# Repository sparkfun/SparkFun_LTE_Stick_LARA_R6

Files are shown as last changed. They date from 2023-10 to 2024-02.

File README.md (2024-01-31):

SparkFun LTE Stick - LARA-R6
========================================

SparkFun LTE Stick - LARA-R6 (https://www.sparkfun.com/products/23618)

[*SparkFun LTE Stick - LARA-R6 (CEL-23618)*](https://www.sparkfun.com/products/23618)

The SparkFun LTE Stick provides a development and prototyping platform for the LARA-R6 LTE Cat 1 module from u-blox<sup>&trade;</sup>. The LTE Stick uses the LARA-R6401 version, which supports both data and voice for North America and works with LTE bands used by these mobile networks: AT&T, Verizon, T-Mobile, and FirstNet. The board includes a nanoSIM card slot for users to select their preferred network. Check with your network provider for compatibility with the LARA-R6.

The LTE Stick routes the UART and I<sup>2</sup>S interfaces to a 0.1in.-spaced plated-through-hole (PTH) header along with the Reset and Power On signals. The board has two SMA connectors for the LARA-R6's primary and secondary antennas. The primary antenna sends and receives data, whereas the secondary antenna is receive only. Power to the board is provided either over the USB-C connector (recommended) or the VIN PTH pin (<b>6V Max</b>). The board defaults to use the higher voltage input. The board also includes test points for advanced users to solder to for the I<sup>2</sup>C interface, secondary UART, and four GPIO pins (IO1, IO2, IO3, and IO6).

Repository Contents
-------------------

* **/Documents** - Datasheets, additional product information 
* **/Examples** - Example code 
* **/Hardware** - Eagle design files (.brd, .sch)
* **/Production** - Production panel files (.brd)
* **/docs** - Documentation files for the LTE Stick - LARA-R6

Documentation
--------------

* **[Hookup Guide](https://docs.sparkfun.com/SparkFun_LTE_Stick_LARA_R6)** - Basic hookup guide for the SparkFun LTE Stick - LARA-R6.
* **[SparkFun u-blox Cellular Arduino Library](https://github.com/sparkfun/SparkFun_u-blox_Cellular_Arduino_Library)** - Arduino library for u-blox cellular modules including the LARA-R6.

Product Versions
----------------
* [CEL-23618](https://www.sparkfun.com/products/23618) - Initial release

License Information
-------------------

This product is _**open source**_! 

Please review the LICENSE.md file for license information. 

If you have any questions or concerns on licensing, please contact technical support on our [SparkFun forums](https://forum.sparkfun.com/viewforum.php?f=152).

Distributed as-is; no warranty is given.

- Your friends at SparkFun.

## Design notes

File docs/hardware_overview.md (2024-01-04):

---
icon: material/cog
---

## LARA-R6 LTE Module

The heart of the LTE Stick is the LARA-R6 LTE Cat 1 module from u-blox. The LARA-R6401 supports data, SMS, <i>and</i> voice over LTE bands and works with most major North American carriers (Verizon, TMobile, AT&T, etc.). 

<figure markdown>
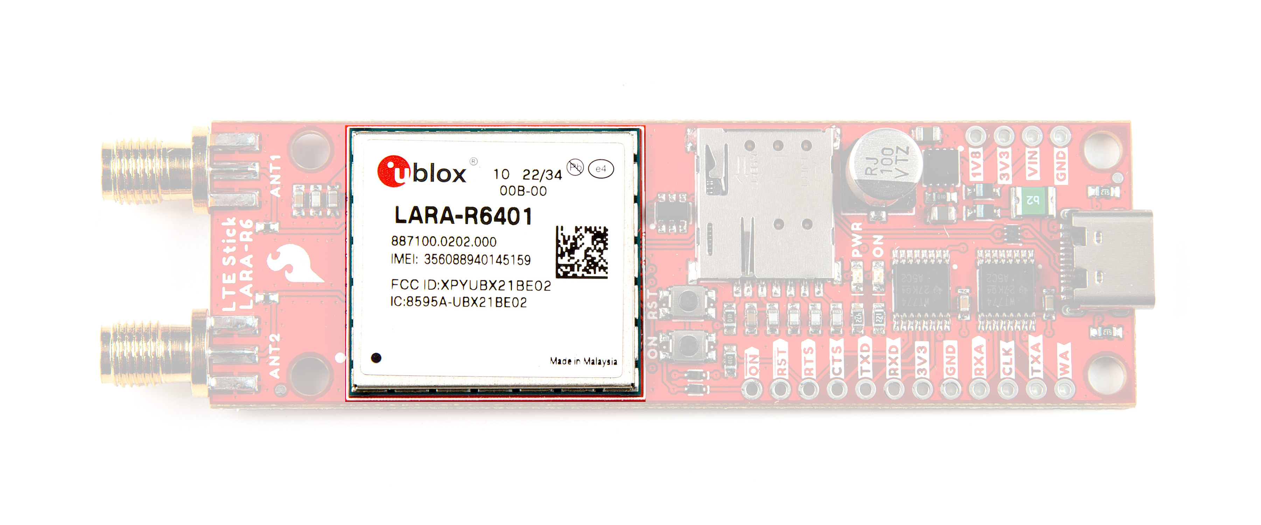
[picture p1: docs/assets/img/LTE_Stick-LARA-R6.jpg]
Highlighting the LARA-R6

</figure>

The LARA-R6 has the following interfaces: USB, 2x UART, I<sup>2</sup>S, I<sup>2</sup>C, SIM interface, and nine GPIO pins. It also has a host of features including device security through Root of Trust (RoT) with secure boot and update, firmware updates both over the air (uFOTA) and through AT commands, dynamic antenna tuning, jamming detection, and much more. For a complete overview of these features and other information on the LARA-R6401, refer to the [datasheet](./assets/component_documentation/LARA-R6-Datasheet.pdf). The R6401 supports LTE FDD bands from 600 MHz to 1900 MHz (2, 4, 5, 12, 13, 14, 66, and 71).

## Pinout

The board breaks out the LARA-R6's UART and I<sup>2</sup>S interfaces as well as the Power On, Reset and voltage pins to a pair of 0.1"-spaced PTH (plated through-hole) headers.

<figure markdown>
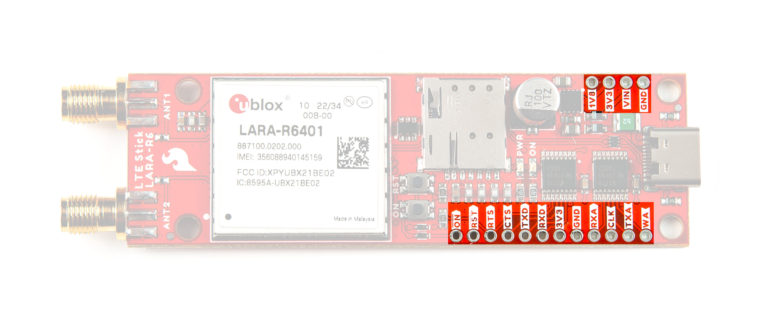
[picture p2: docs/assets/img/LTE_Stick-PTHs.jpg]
Highlighting PTH pinout

</figure>

The list below outlines the functionality of pins broken out on the LTE Stick:

  * PWR_On - LARA-R6 power control pin
  * Reset - LARA-R6 reset pin
  * RXD - UART data out
  * TXD - UART data in
  * CTS - UART clear to send
  * RTS - UART ready to send
  * RXA - I<sup>2</sup>S receive data
  * CLK - I<sup>2</sup>S clock
  * TXA - I<sup>2</sup>S transmit data
  * WA - I<sup>2</sup>S word alignment

  * VIN - 5V 
  * 3.3V - Regulated 3.3V
  * 1.8 - Regulated 1.8V  
 
### Test Points

!!! warning
	All three of these clusters have test point connections for <b>1.8V</b> and <b>GND</b> and connect directly to the associated pins on the LARA-R6. These pins are <i>not</i> level-shifted and run at <b>1.8V</b> logic. Take care when interacting with these pins to avoid damaging the signals they connect to.

The LTE Stick also has several other interfaces broken out to test points for advanced users to solder to. These test points are small copper pads grouped into three clusters labeled: <b>I2C</b>, <b>GPIO</b>, and <b>UART2</b>. They do not have individual pin labels so refer to the [board files (ZIP)](./assets/board_files/SparkFun_LTE_Stick_LARA_R6.zip) to identify the pin locations.

<figure markdown>
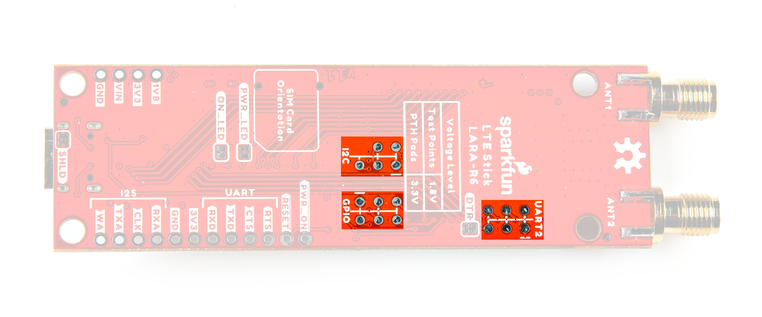
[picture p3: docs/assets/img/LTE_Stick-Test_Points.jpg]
Highlighting the test point clusters

</figure>

The I2C cluster contains the LARA's I<sup>2</sup>C bus pins (SDA/SCL) as well as GPIO4. The GPIO cluster contains GPIO1, GPIO2, GPIO3, and GPIO6. All GPIO pins can act as a generic GPIO signal but some have alternate functions outlined in section 2.8 of the [LARA-R6 datasheet](./assets/component_documentation/LARA-R6-Datasheet.pdf). 

The UART2 cluster contains the LARA's UART2 pins: TX2, RX2, CTS2, and RTS2. This interface is disabled by default and can be activated by the dedicated AT command. Refer to section 18.12 of the [AT commands manual](./assets/component_documentation/LARA-R6-L6-AT-Commands.pdf) and section 1.9.1.2 of the [integration manual](./assets/component_documentation/LARA-R6-L6-Integration-Manual.pdf) for complete information on using these pins. Users also should open the <b>DTR</b> solder jumper to use this pin for TX2 (refer to the Solder Jumpers section for more information on the DTR jumper).

## Connectors/Connections

Let's take a closer look at the connectors on the LTE Stick.

### Power

The LTE Stick uses a USB-C connector for primary power input and serial communication. The board also has dedicated PTHs for the three voltage inputs on the board: <b>5V(VIN)</b>, <b>3.3V</b>, and <b>1.8V</b> along with PTHs for Ground.

<figure markdown>
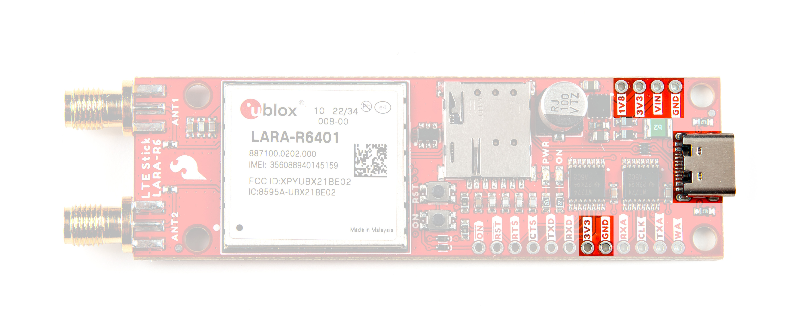
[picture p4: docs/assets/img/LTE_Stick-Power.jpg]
Highlighting the USB-C connector & power PTHs

</figure>

### Antenna Connections

The LARA-R6 has two antenna connections; Primary (ANT1) and Secondary (ANT2). The Primary antenna functions as the main antenna interface and supports TX/RX transmissions. The Secondary antenna communicates over RX only for the LTE / 3G RX diversity configuration. 

<figure markdown>
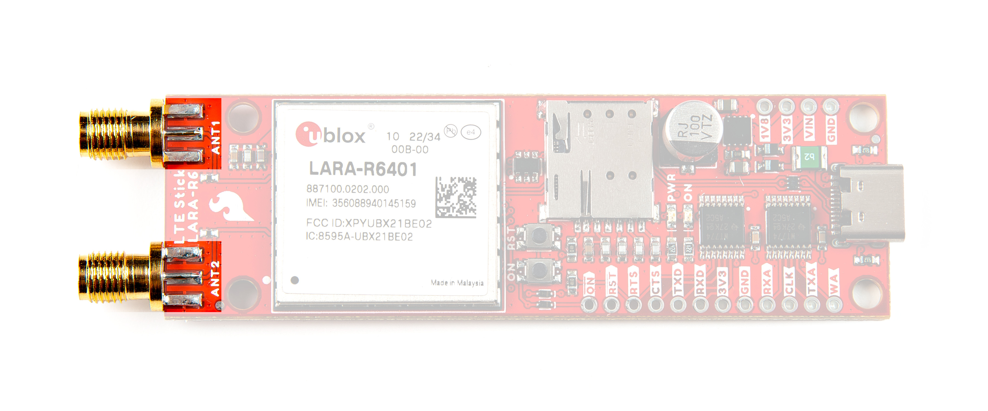
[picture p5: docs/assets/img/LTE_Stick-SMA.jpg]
Highlighting the antenna SMA connectors

</figure>

### Nano SIM Card Slot

The LTE Stick has an on-board Nano SIM card slot. The LTE Stick uses the LARA-R6401 which works with most major North American carriers (Verizon, TMobile, AT&T, etc.).   

<figure markdown>
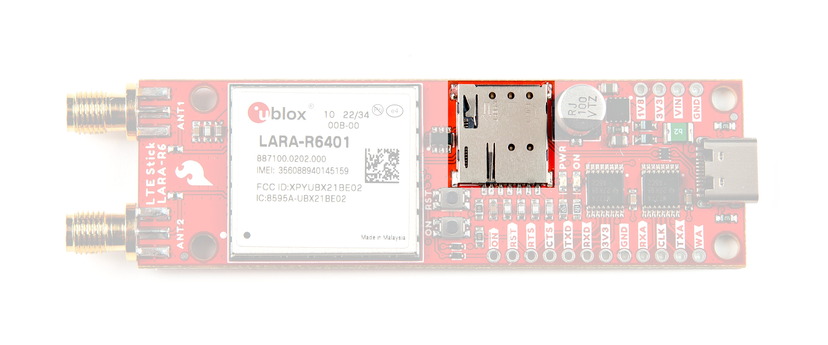
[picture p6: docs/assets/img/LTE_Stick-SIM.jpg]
Highlighting the nano SIM card slot

</figure>

## Buttons

The board has two buttons labeled <b>ON</b> and <b>RST</b>. The <b>ON</b> button connects to the LARA-R6 PWR_On pin which turns the module on and off. Tap it once to turn the module on and hold it down for three seconds to turn it off. The <b>RST</b> button connects to the LARA-R6's reset line and resets the module when pressed.

<figure markdown>
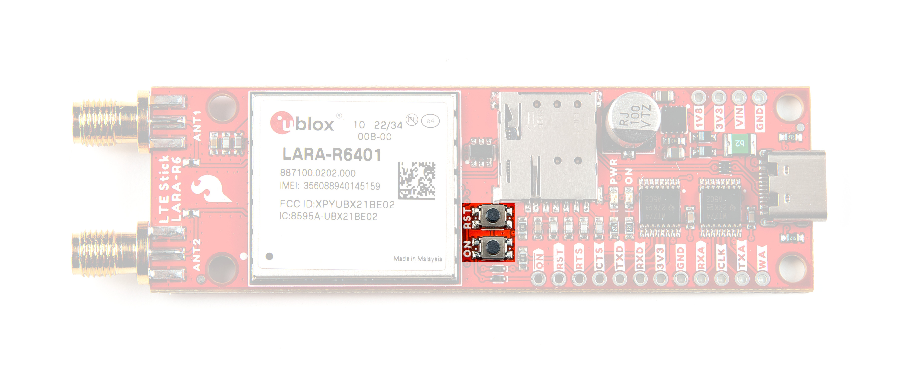
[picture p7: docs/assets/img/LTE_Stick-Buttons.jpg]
Highlighting the Reset and On buttons

</figure>

## LEDs

The LTE Stick has a pair of red LEDs labeled <b>PWR</b> and <b>ON</b>. The <b>PWR</b> LED indicates whenever the 3.3V rail is powered through USB or the VIN/3.3V PTH pins. The <b>ON</b> LED indicates when the LARA-R6 is powered up. 

<figure markdown>
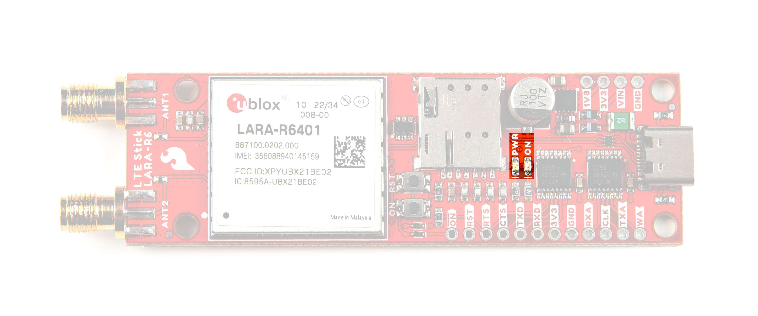
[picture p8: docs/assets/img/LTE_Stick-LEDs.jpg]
Highlighting the Power and On LEDs

</figure>

## Solder Jumpers

??? note "Never modified a jumper before?"
	Check out our <a href="https://learn.sparkfun.com/tutorials/664">Jumper Pads and PCB Traces tutorial</a> for a quick introduction!
	<p align="center">
		<a href="https://learn.sparkfun.com/tutorials/664">
		Tutorial's thumbnail<br>
        How to Work with Jumper Pads and PCB Traces</a>
	</p>

The LTE Stick has four solder jumpers labeled <b>PWR_LED</b>, <b>ON_LED</b>, <b>SHLD</b>, and <b>DTR</b>. 

<figure markdown>
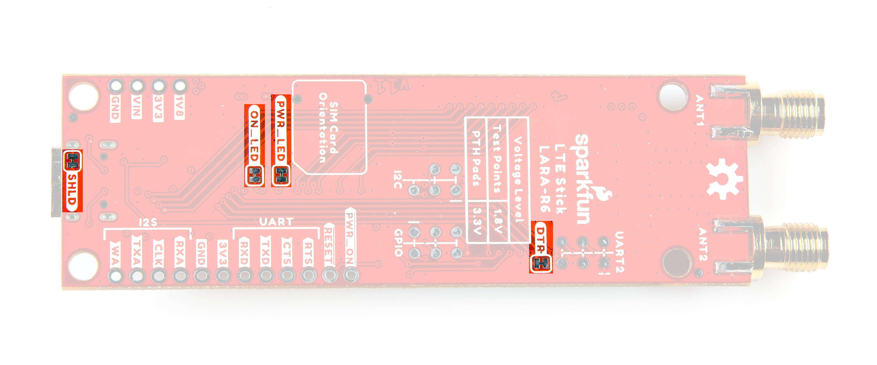
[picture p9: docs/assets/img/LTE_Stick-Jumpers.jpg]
Highlighting the solder jumpers

</figure>

The <b>PWR_LED</b> and <b>ON_LED</b> jumpers complete the power circuits for their associated LEDs (PWR and ON). They are CLOSED by default. Open them to disable these LEDs to help conserve power. The <b>SHLD</b> jumper connects the USB-C connector's shield pin to ground. Open it to isolate the shield pin. The <b>DTR</b> jumper is CLOSED by default and pulls the LARA-R6 DTR pin to ground (LOW) to function as UART data terminal ready. Open the jumper to use the DTR pin for its secondary use as TX2 when using the UART2 test point cluster.

## Board Dimensions

The board measures 3.25" x 1.00" (82.55mm x 25.40mm) with four mounting holes that fit a [4-40 screw](https://www.sparkfun.com/products/10453).

<figure markdown>
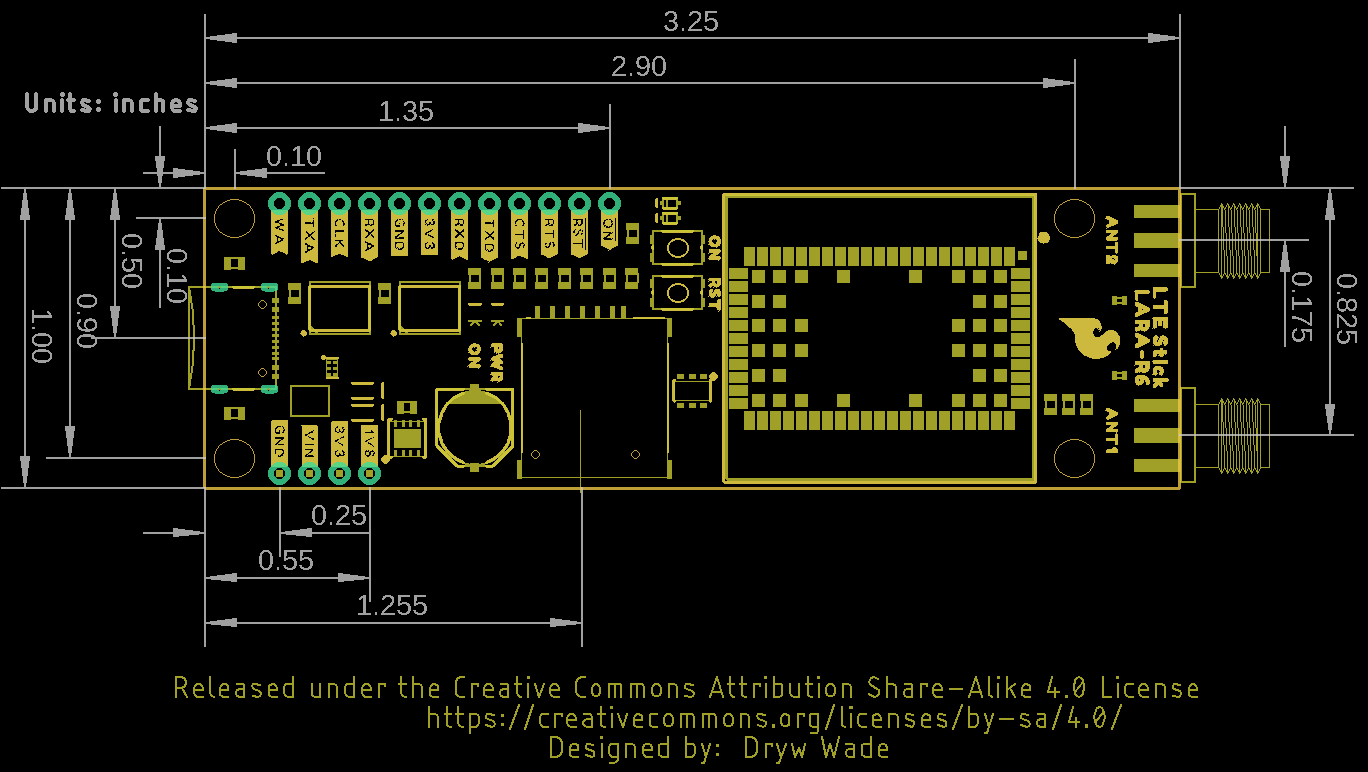
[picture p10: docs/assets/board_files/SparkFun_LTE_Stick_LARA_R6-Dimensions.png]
Board Dimensions

<figcaption markdown>
[Board dimensions](./assets/board_files/SparkFun_LTE_Stick_LARA_R6-Dimensions.png) for the SparkFun LTE Stick, in inches.
</figcaption>
</figure>

??? tip "Need more measurements?"
	For more information about the board's dimensions, users can download the [Eagle files](./assets/board_files/SparkFun_LTE_Stick_LARA_R6.zip) for the board. These files can be opened in Eagle and additional measurements can be made with the dimensions tool.

	??? info ":octicons-download-16:{ .heart } Eagle - Free Download!"
		Eagle is a [CAD]("computer-aided design") program for electronics that is free to use for hobbyists and students. However, it does require an account registration to utilize the software.

		<center>
		[Download from<br>:autodesk-primary:{ .autodesk }](https://www.autodesk.com/products/eagle/free-download "Go to downloads page"){ .md-button .md-button--primary width="250px" }
		</center>
	
	??? info ":straight_ruler: Dimensions Tool"
		This video from Autodesk demonstrates how to utilize the dimensions tool in Eagle, to include additional measurements:

		<center>
		<div class="video">
		<iframe src="https://www.youtube.com/embed/dZLNd1FtNB8" title="EAGLE Dimension Tool" frameborder="0" allow="accelerometer; autoplay; clipboard-write; encrypted-media; gyroscope; picture-in-picture" allowfullscreen></iframe>
		</div>
		</center>

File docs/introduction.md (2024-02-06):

---
icon: material/book-open-page-variant
---

<div class="grid cards desc" markdown>

-    <a href="https://www.sparkfun.com/products/23618">
    **SparkFun LTE Stick - LARA-R6**<br>
    **SKU:** CEL-23618

    ---

    <figure markdown>
    Product Thumbnail
    </figure></a>

    <center>
    <article class="video_desc">
    <iframe src=" https://www.youtube.com/embed/hY0C0PU3CvQ" title="Product Showcase: SparkFun LTE Stick - LARA-R6" frameborder="0" allow="accelerometer; autoplay; clipboard-write;encrypted-media; gyroscope; picture-in-picture" allowfullscreen></iframe>
    </article>
    </center>

-    The SparkFun LTE Stick - LARA-R6 is a development and prototyping platform for the LARA-R6401 LTE module from ublox<sup>&trade;</sup>. The LTE Stick uses the LARA-R6401 version which supports both data and voice for North America and works with LTE bands used by these mobile networks: AT&T, Verizon, T-Mobile, and FirstNet. The board includes a nanoSIM card slot for users to select their preferred network. Check with your network provider for compatibility with the LARA-R6.

    The LARA-R6 workss on multiple LTE FDD frequency bands (2, 4, 5, 12, 13, 14, 66, and 71) and includes a host of common features users expect from u-blox modules including uFOTA (over-the-air firmware update), Root of Trust, secure boot/update, jamming detection, antenna and SIM detection, and much more. 
    
    The LTE Stick routes the UART and I<sup>2</sup>S interfaces to a 0.1"-spaced plated-through-hole (PTH) header along with the Reset and Power On signals and we designed the board to specifically mount on to a breadboard for easy prototyping. The board has two SMA connectors for the LARA-R6's primary and secondary antennas.

    <center>
    [Purchase from SparkFun :fontawesome-solid-cart-plus:{ .heart }](https://www.sparkfun.com/products/23618){ .md-button .md-button--primary }
    </center>

</div>

## Required Materials

The LTE Stick requires a few peripheral items including antennas, USB-C cable, and supported SIM card to get it up and running. Below are a few recommended options for each.

### USB-C Cable

For basic use and conifguration of the LTE Stick using AT commands or u-blox's m-center software you'll need USB-C cable to connect the dev board to your computer:

<div class="grid cards" markdown>

-   <a href="https://www.sparkfun.com/products/14743">

    <figure markdown>
    USB 3.1 Cable A to C - 3 Foot
    </figure>
    </a>
    ---
    <a href="https://www.sparkfun.com/products/14743">
    **USB 3.1 Cable A to C - 3 Foot**<br>
    CAB-14743
    </a>

-   <a href="https://www.sparkfun.com/products/15424">
    
    <figure markdown>
    Reversible USB A to C Cable - 2m
    </figure>
    </a>
    ---
    <a href="https://www.sparkfun.com/products/15424">
    **Reversible USB A to C Cable - 2m**<br>
    CAB-15424
    </a>
</div>

### LTE Antenna

The LTE Stick has two SMA connectors for the Primary and Secondary antenna signals on the LARA-R6. The LARA-R6 only requires the Primary antenna for basic functionality but u-blox recommends connecting the Secondary antenna for best signal quality. We recommend using an antenna like the one below:

<div class="grid cards" markdown>

-   <a href="https://www.sparkfun.com/products/16432">

    <figure markdown>
    LTE Hinged External Antenna - 698MHz-2.7GHz, SMA Male
    </figure>
    </a>
    ---
    <a href="https://www.sparkfun.com/products/16432">
    **LTE Hinged External Antenna - 698MHz-2.7GHz, SMA Male**<br>
    CEL-16432
    </a>
</div>

### SIM Card

Finally, the LTE Stick requires a nano SIM card for cellular network connectivity. As mentioned above, the LTE Stick uses the LARA-R6401 module and supports <i>only</i> North American LTE networks and works with the AT&T, Verizon, T-Mobile, and FirstNet cellular networks though make sure to check with your selected network provider for compatibility with the LARA-R6 before purchasing. The Hologram SIM card listed below works with the LARa-R6 for data and receiving SMS but not voice or sending SMS:

<div class="grid cards" markdown>

-   <a href="https://www.sparkfun.com/products/17117">

    <figure markdown>
    Hologram SIM Card
    </figure>
    </a>
    ---
    <a href="https://www.sparkfun.com/products/17117">
    **Hologram SIM Card**<br>
    CEL-17117
    </a>
</div>

## Optional Materials

Using the LTE Stick with the SparkFun u-blox Cellular Arduino Library requires a connection to a microcontroller/development board. Below are a few options that will work with the LTE Stick out of the box.

### Development Boards

??? warning "Logic Levels"
    The LTE Stick operates at <b>3.3V</b> logic so make sure your chosen development board operates at the same logic level or use a [level shifter](https://www.sparkfun.com/categories/361).

<div class="grid cards" markdown>

-   <a href="https://www.sparkfun.com/products/20168">

    <figure markdown>
    SparkFun Thing Plus - ESP32 WROOM (USB-C)
    </figure>
    </a>
    ---
    <a href="https://www.sparkfun.com/products/20168">
    **SparkFun Thing Plus - ESP32 WROOM (USB-C)**<br>
    DEV-20168
    </a>

-   <a href="https://www.sparkfun.com/products/19177">

    <figure markdown>
    SparkFun IoT RedBoard - ESP32 Development Board
    </figure>
    </a>
    ---
    <a href="https://www.sparkfun.com/products/19177">
    **SparkFun IoT RedBoard - ESP32 Development Board**<br>
    DEV-19177
    </a>

-   <a href="https://www.sparkfun.com/products/15574">
    
    <figure markdown>
    SparkFun Thing Plus - Artemis
    </figure>
    </a>
    ---
    <a href="https://www.sparkfun.com/products/15574">
    **SparkFun Thing Plus - Artemis**<br>
    DEV-18158
    </a>

-   <a href="https://www.sparkfun.com/products/20168">

    <figure markdown>
    SparkFun Qwiic Pocket Development Board - ESP32-C6
    </figure>
    </a>
    ---
    <a href="https://www.sparkfun.com/products/22925">
    **SparkFun Qwiic Pocket Development Board - ESP32-C6**<br>
    DEV-22925
    </a>

-   <a href="https://www.sparkfun.com/products/23386">

    <figure markdown>
    SparkFun ESP32 Qwiic Pro Mini
    </figure>
    </a>
    ---
    <a href="https://www.sparkfun.com/products/23386">
    **SparkFun ESP32 Qwiic Pro Mini**<br>
    DEV-23386
    </a>

-   <a href="https://www.sparkfun.com/products/15444">

    <figure markdown>
    SparkFun RedBoard Artemis
    </figure>
    </a>
    ---
    <a href="https://www.sparkfun.com/products/15444">
    **SparkFun RedBoard Artemis**<br>
    DEV-15444
    </a>    
</div>

If you prefer to use the LTE Stick with a development board or simply prefer a soldered connection or want to modify the solder jumpers on these Qwiic breakouts you you may need some of the products listed below:

## Soldering Tools & Accessories

<div class="grid cards" markdown align="center">

-   <a href="https://www.sparkfun.com/products/116">

    <figure markdown>
    Break Away Headers - Straight)
    </figure>
    </a>
    ---
    <a href="https://www.sparkfun.com/products/116">
    **Break Away Headers - Straight**<br>
    PRT-00116
    </a>

-   <a href="https://www.sparkfun.com/products/14681">
    
    <figure markdown>
    SparkFun Beginner Tool Kit
    </figure>
    </a>
    ---
    <a href="https://www.sparkfun.com/products/14681">
    **SparkFun Beginner Tool Kit**<br>
    TOL-14681
    </a>

-   <a href="https://www.sparkfun.com/products/22133">

    <figure markdown>
    Weller WLSK3012A Soldering Station
    </figure>
    ---
    <a href="https://www.sparkfun.com/products/22133">**Weller WLSK3012A Soldering Station**<br>
    TOL-22133
    </a>

-   <a href="https://www.sparkfun.com/products/9325">

    <figure markdown>
    Solder Lead Free - 100-gram Spool
    </figure>
    ---
    <a href="https://www.sparkfun.com/products/9325">**Solder Lead Free - 100-gram Spool**<br>
    TOL-09325
    </a>

-   <a href="https://www.sparkfun.com/products/9200">
    
    <figure markdown>
    Hobby Knife
    </figure>
    </a>
    ---
    <a href="https://www.sparkfun.com/products/9200">
    **Hobby Knife**<br>
    TOL-09200
    </a>

-   <a href="https://www.sparkfun.com/products/14579">

    <figure markdown>
    Chip Quik No-Clean Flux Pen - 10mL
    </figure>
    </a>
    ---
    <a href="https://www.sparkfun.com/products/14579">**Chip Quik No-Clean Flux Pen - 10mL**<br>
    CAB-14579
    </a>
</div>

## Suggested Reading

Before getting started with this Hookup Guide, you may want to read through the tutorials below if you are not familiar with the concepts covered in them or want a refresher. If you are using either of the Qwiic Shields linked above, we recommend reading through their respective Hookup Guides before continuing with this tutorial:

<div class="grid cards hide col-4" markdown align="center">

-   <a href="https://learn.sparkfun.com/tutorials/8">
    <figure markdown>
    Serial Communication
    </figure>
    </a>
    <a href="https://learn.sparkfun.com/tutorials/8">**Serial Communication**
    </a>

-   <a href="https://learn.sparkfun.com/tutorials/62">
    <figure markdown>
    Logic Levels
    </figure>
    </a>
    <a href="https://learn.sparkfun.com/tutorials/62">**Logic Levels**
    </a>

-   <a href="https://learn.sparkfun.com/tutorials/61">
    <figure markdown>
    Installing Arduino IDE
    </figure>
    </a>
    <a href="https://learn.sparkfun.com/tutorials/61">**Installing Arduino IDE**
    </a>

-   <a href="https://learn.sparkfun.com/tutorials/15">
    <figure markdown>
    Installing an Arduino Library
    </figure>
    </a>
    <a href="https://learn.sparkfun.com/tutorials/15">**Installing an Arduino Library**
    </a>

-   <a href="https://learn.sparkfun.com/tutorials/112">
    <figure markdown>
    Serial Terminal Basics
    </figure>
    </a>
    <a href="https://learn.sparkfun.com/tutorials/112">**Serial Terminal Basics**
    </a>

-   <a href="https://learn.sparkfun.com/tutorials/664">
    <figure markdown>
    How to Work with Jumper Pads and PCB Traces
    </figure>
    </a>
    <a href="https://learn.sparkfun.com/tutorials/664">**How to Work with Jumper Pads and PCB Traces**
    </a>
</div>

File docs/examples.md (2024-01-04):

---
icon: simple/arduino
---

The SparkFun u-blox Cellular Arduino Library includes a large set of examples to do all sorts of things with supported u-blox cellular modules. Some examples work with all modules, others are limited to specific ones. All examples assume a serial connection between a microcontroller and the LTE Stick (or other supported cellular module) as demonstrated in the Hardware Assembly section. These examples build upon each other so we recommend following them in sequential order to get everything set up and working properly.

!!! note "LARA-R6 Power"
	Make sure to power on the module using the "ON" button 

If you have not used m-center or AT commands to configure the network information and register the network operator for your device before using this library, you may need to go through Example 2 - Network Info and Example 3 - Register Operator to get the LARA-R6 registered and configured properly on your network. Otherwise, feel free to skip ahead to the Ping and other more complex examples.

## Example 1 - Device Identification

The first example  performs the basic AT commands to return the device information of a connected module:

* Manufacturer ID
* Model
* Firmware Version
* Serial Number
* IMEI ID
* IMSI ID
* SIM CCID
* Subscriber Number (from the SIM)
* Capabilities
* SIM state

Open the example by navigating to <b>File < Examples < SparkFun u-blox Cellular Arduino Library < Example 1 - Device Identification</b> or copy the code below into a blank sketch.

??? "Example 1 - Device Information"
	```
	--8<-- "https://raw.githubusercontent.com/sparkfun/SparkFun_u-blox_Cellular_Arduino_Library/main/examples/Example1_DeviceIdentification/Example1_DeviceIdentification.ino"
	```

!!! warning "Serial Port Selection"
	This and all following examples default to use <code>Serial1</code> for serial communication between the LTE Stick and microcontroller. If your selected microcontroller does not have this serial port, uncomment the following line and, if necessary, adjust the pins set for software serial depending on the [software serial library limitations](https://docs.arduino.cc/learn/built-in-libraries/software-serial).

	```c++
		// SoftwareSerial mySerial(16, 17);
	```

Select your board (SparkFun Thing Plus ESP32 if you're following along with this tutorial verbatim) and Port and click the "Upload" button. When the code finishes compiling and uploading, open the [serial monitor](https://learn.sparkfun.com/tutorials/terminal-basics/arduino-serial-monitor-windows-mac-linux) with the baud set to <b>115200</b>. The code waits on a user prompt to begin so press any key when prompted in the serial monitor and you should see the device information and SIM status print out.

## Example 2 - Network Info

The second example verifies the LARA-R6 is receiving an LTE signal on a selected network and prints out the network information and IDs. The code creates the LARA-R6 object and assigns a network operator value.

??? "Example 2 -Network Info"
	```
	--8<-- "https://raw.githubusercontent.com/sparkfun/SparkFun_u-blox_Cellular_Arduino_Library/main/examples/Example2_NetworkInfo/Example2_NetworkInfo.ino"
	```

After uploading the code, open a terminal window with the baud set to <b>115200</b> and enter any key to start the example. After initializing everything needed, the code attempts to set the Network Profile to the Mobile Network Operator entered. If successful, the code prints out the RSSI (Received Signal Strength), Network Registration Status and Context IDs, Access Point Names and IP Addresses.

## Example 3 - Register Operator

Example 4 checks to see if the LARA-R6 is connected to a network and lets you register on a different network if available and if the SIM supports this. This example can also be used to list all the LTE operators the LARA-R6 can detect. Note, you can only connect to networks supported by your SIM card. Refer to your SIM card manufacturer's documentation for supported networks.

??? "Example 3 - Register Operator"
	```
	--8<-- "https://raw.githubusercontent.com/sparkfun/SparkFun_u-blox_Cellular_Arduino_Library/main/examples/Example3_RegisterOperator/Example3_RegisterOperator.ino"
	```	

## Example 5 - Ping

The eighth example tests the LTE Stick's data connection by a standard server ping. Open a terminal window and follow the prompts then enter a server to ping. Any valid web address like <b>www.google.com</b> or <b>www.sparkfun.com</b> works. If the ping succeeds the code prints out the time to send and receive the ping in milliseconds.

??? "Example 5 - Ping"
	```
	--8<-- "https://raw.githubusercontent.com/sparkfun/SparkFun_u-blox_Cellular_Arduino_Library/main/examples/Example5_Ping/Example5_Ping.ino"
	```

If the ping fails, try uncommenting this line that enables debugging over serial:

```c++
// myModule.enableDebugging(); // Uncomment this line to enable helpful debug messages on Serial
```

Upload the code again, retry the ping and look for any messages that include +UUPINGER:. Refer to the list of Ping error codes in Appendix A. 9 of the [AT Command Reference](./assets/component_documentation/LARA-R6-L6-AT-Commands.pdf) to decipher the error code.

## Further Examples

These examples perform the basic tests for making sure everything is working properly on the LTE Stick but the SparkFun u-blox Cellular Arduino Library includes many more examples to take full advantage of the LARA-R6's capabilities including audio examples for playing audio tones and phonecall control. The audio examples require external hardware including an audio codec and are beyond the scope of this tutorial.

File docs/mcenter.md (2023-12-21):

The m-center application from u-blox is an excellent configuration and interaction tool for the LARA-R6 (and other cellular modules). It is only available on Windows so if you have a different operating system, you'll need to use another software solution like the SparkFun u-blox AT Command Arduino Library covered in the next sections. This section only covers a few of the basics to get started using the LTE Stick with m-center. Refer to u-blox's [m-center User Guide](https://www.u-blox.com/en/m-center-user-guide) for a complete overview of all of the application's features.

## Download m-center

The m-center application is available from u-blox [here](https://www.u-blox.com/en/product/m-center). Click the button on that page to download the installer. Locate that file and follow the instructions to finish the installation process.

<center>
[u-blox m-center](https://www.u-blox.com/en/product/m-center){ .md-button .md-button--primary }
</center>

### Download Windows Drivers

The LARA-R6 also requires a Windows USB driver download. Find it on u-blox's [LARA-R6 Documentation & Resources](https://www.u-blox.com/en/product/lara-r6-series?legacy=Current#Documentation-&-resources) page or download the driver ZIP directly by clicking the button below:

<center>
[u-blox LARA-R6 Windows Driver (ZIP)](https://content.u-blox.com/sites/default/files/2023-10/ublox_R4_R6_L6_windows_3264_v2.0.0.0.zip){ .md-button .md-button--primary }
</center>

Open the file once it downloads and follow the instructions to complete the driver installation.

## Basic LTE Stick Connection & Testing

Now that everything is downloaded connect the LTE Stick over USB and press the "On" button to power up the LARA-R6, open m-center and you'll see this menu:

<div markdown>
<figure markdown>
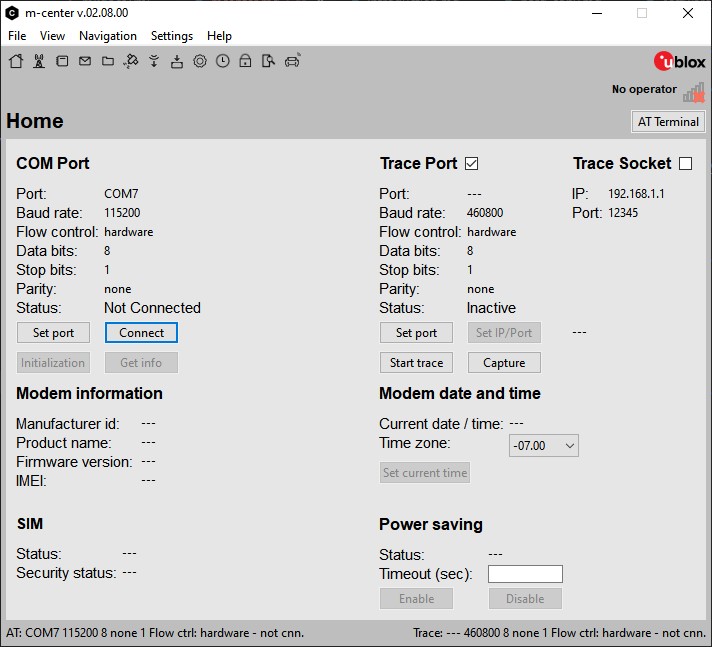
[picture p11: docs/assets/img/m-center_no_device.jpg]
Main m-center menu

</figure>
</div>

Next, click the "Set Port" button to select the COM port the LTE Stick is on. The LTE Stick has four port options in this menu as the screenshot below shows. Select the one for USB1 (labeled "u-blox Modem USB1 AT and Data (COM#) or similar) and click "Connect". If you do not see any devices available or see unrelated ports, make sure the "ON" LED is illuminated on the LTE Stick and that the drivers finished installing.

<div markdown>
<figure markdown>
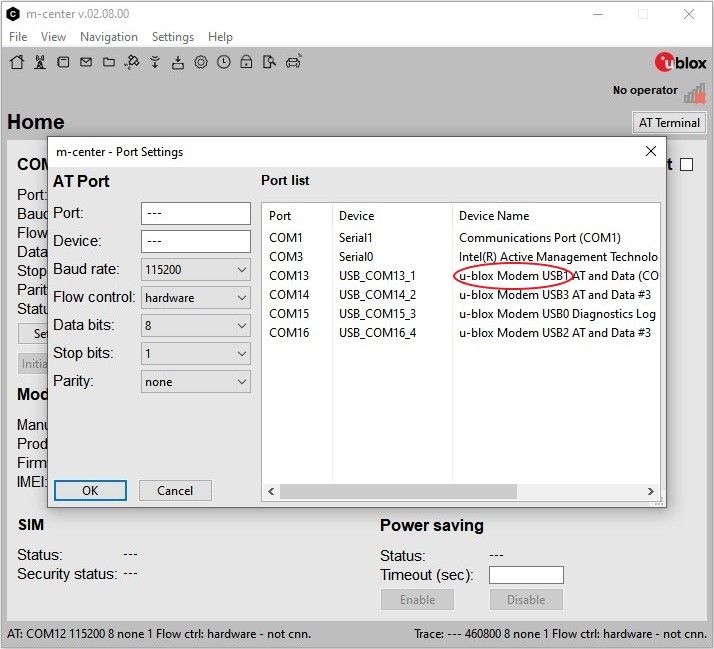
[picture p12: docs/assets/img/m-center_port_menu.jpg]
Main m-center menu

</figure>
</div>

After the board connects, m-center will display the LARA-R6's modem information including manufacturer, device ID, and firmware version. It also opens the terminal interface and prints out the device's response to the Generic set of AT commands similar to the screenshot below:

<div markdown>
<figure markdown>
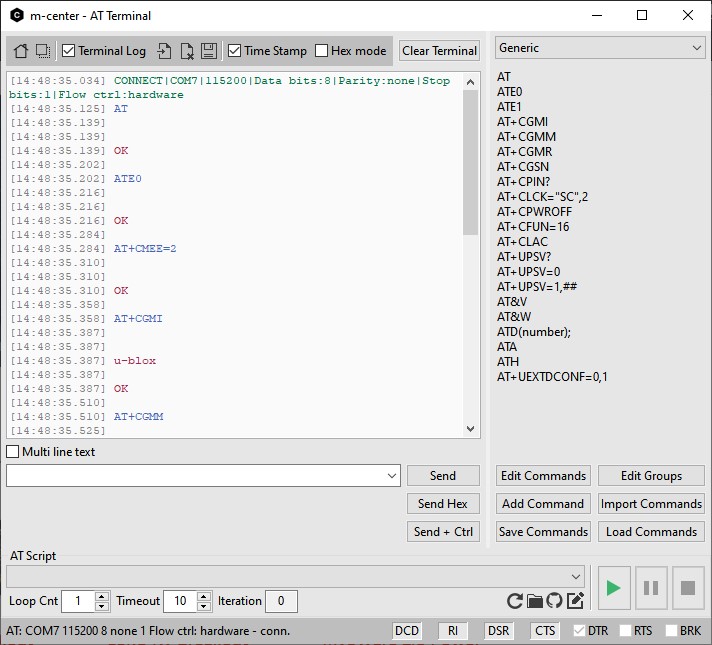
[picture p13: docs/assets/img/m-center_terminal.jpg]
Main m-center menu

</figure>
</div>

This basic printout lets you know most things are working but the main m-center menu also has several tabs at the top for testing other things such as network connection, firmware update (FOTA or AT command), SMS messages, and more. You can also click the "Initialization" button to initialize the LARA-R6 again or the "Get info" button to refresh the modem information and SIM status.

## Network & Operator Setup

Now that we have the LTE Stick connected and reporting the correct device information, it's time to connect to the cellular network and select the operator. Click the "Cell Tower" image in the top left to switch to the Network tab. In this tab, we can get the network information and operators list as well as the PSD (packet-switched-data profiles) though the PSD profiles are not necessary for basic use of the LARA-R6.

<div markdown>
<figure markdown>
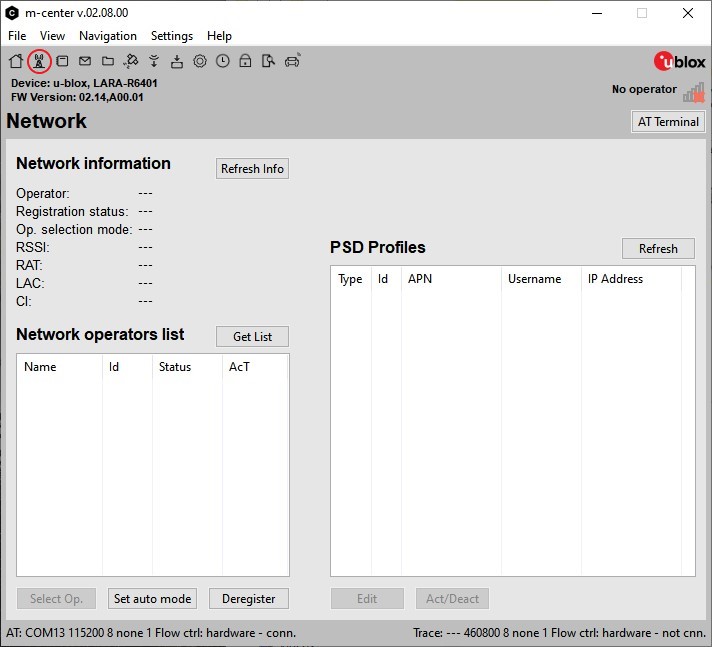
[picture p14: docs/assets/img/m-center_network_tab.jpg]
Main m-center menu

</figure>
</div>

Click the "Get List" button to have the LARA-R6 report all available network operators for the connected SIM card. If no operators are selected, choose an available/preferred operator and you're all set to move on to using the LTE Stick on your cellular network. 

<div markdown>
<figure markdown>
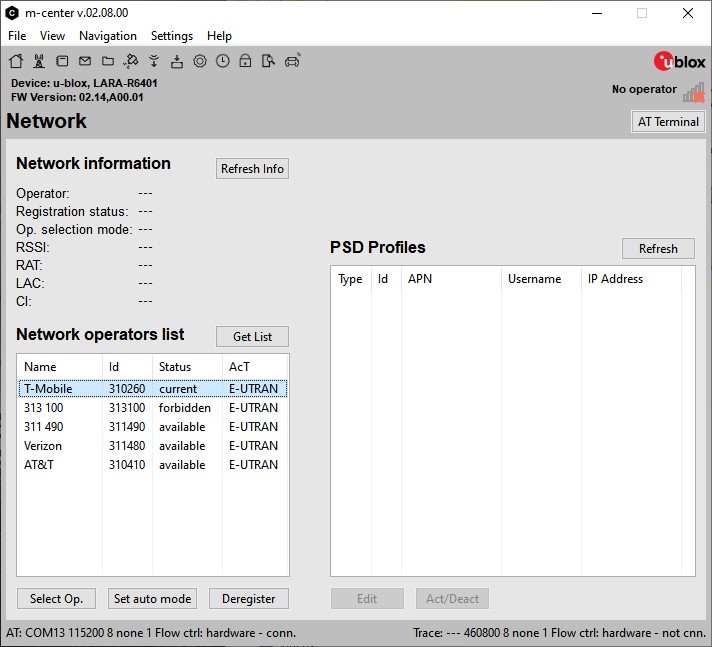
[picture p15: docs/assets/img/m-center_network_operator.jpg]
Main m-center menu

</figure>
</div>

That covers the basics of getting started with m-center. For more information, check out u-blox's [m-center user guide](https://www.u-blox.com/en/m-center-user-guide) or read on to the next section to learn how to use the LTE Stick with Arduino and the SparkFun u-blox Cellular Arduino Library.

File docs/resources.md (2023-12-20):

# Resources
For more resources related to the LTE Stick - LARA-R6, check out the links listed here: 

<b>LTE Stick Resources:</b>

* [Product Page](https://www.sparkfun.com/products/23618)
* [Schematic](./assets/board_files/SparkFun_LTE_Stick_LARA_R6.pdf)
* [Eagle Files](./assets/board_files/SparkFun_LTE_Stick_LARA_R6.zip) 
* [Board Dimensions]()
* [SparkFun u-blox Cellular Arduino Library](https://github.com/sparkfun/SparkFun_u-blox_Cellular_Arduino_Library)
* [Hardware GitHub Respository](https://github.com/sparkfun/SparkFun_LTE_Stick_LARA_R6)

<b>LARA-R6 Resources:</b>

* [Datasheet](./assets/component_documentation/LARA-R6-Datasheet.pdf)
* [Integration Manual](./assets/component_documentation/LARA-R6-L6-Integration-Manual.pdf)
* [Audio App Note](./assets/component_documentation/LARA-R6-Audio-App-Note.pdf)
* [AT Command Set](./assets/component_documentation/LARA-R6-L6-AT-Commands.pdf)
* [m-center Download](https://www.u-blox.com/en/product/m-center)
* [m-center User Guide](https://www.u-blox.com/en/m-center-user-guide)

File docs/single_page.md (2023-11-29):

---
hide:
  - navigation
  - toc
icon: fontawesome/solid/scroll
---

--8<-- "./docs/introduction.md:5"

# Hardware Overview
--8<-- "./docs/hardware_overview.md:5"

# Hardware Assembly
--8<-- "./docs/hardware_assembly.md:5"

# u-blox Cellular Arduino Library

## Software Setup
--8<-- "./docs/software_setup.md:5"

## Arduino Examples
--8<-- "./docs/examples.md"

# Troubleshooting Tips
--8<-- "./docs/troubleshooting_tips.md:5"

# Resources:
--8<-- "./docs/resources.md"

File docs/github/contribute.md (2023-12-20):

# Contribute: Make an Augmentation!
Spot an improvement opportunity? Feel free to contribute to our open-source design and documentation. 

## :material-file-document-multiple:&nbsp;Improve our Documentation
All of this documentation can be modified by you! Please help us make it better.

* These pages are contained in the [`docs` folder](https://github.com/sparkfun/SparkFun_LTE_Stick_LARA_R6/tree/main/docs) of the [SparkFun LTE Stick - LARA-R6 repository](https://github.com/sparkfun/SparkFun_LTE_Stick_LARA_R6).

<!-- ### :material-source-pull:&nbsp;Submit a Correction -->
### Submit a Correction

1. With a GitHub account, [fork this repository](https://github.com/sparkfun/SparkFun_LTE_Stick_LARA_R6/fork).
2. Add your corrections or improvements to the markdown file.
3. File a pull request with your changes, and enjoy making the ~~words~~ ~~worlds~~ world a better place.
	* Once received, the documentation specialist will automatically be notified.
	* We will review your suggested improvements to make sure they are correct and fit within our documentation standards.

## :material-cog:&nbsp;Improve our Hardware Design
All of our designs are open-source! Please help us make it better.

* Our board design files are contained in the [`Hardware` folder](https://github.com/sparkfun/SparkFun_LTE_Stick_LARA_R6/tree/main/Hardware) of the [SparkFun LTE Stick - LARA-R6 repository](https://github.com/sparkfun/SparkFun_LTE_Stick_LARA_R6).

<!-- ### :material-source-pull:&nbsp;Submit a Design Enhancement -->
### Submit a Design Enhancement

1. With a GitHub account, [fork this repository](https://github.com/sparkfun/SparkFun_LTE_Stick_LARA_R6/fork).
2. Add your design augmentation(s)
3. File a pull request with your changes, and enjoy making the ~~words~~ ~~worlds~~ world a better place.
	1. Once received, the engineer in charge of the original design will automatically be notified.
	2. We will review your suggested improvement(s) to verify that they are within our board design standards and meet our product design requirements.
	3. If approved, we will flag these changes for our next board revision. Congrats! 🍻

		!!! info
			Even if your suggestion is accepted, these changes may not be immediately available for purchase. We may have to cycle through our current product inventory first.

## Contributors&nbsp;:clap:
Let's provide some recognition to the contributors for this project!

GitHub Contributors Image
<br>


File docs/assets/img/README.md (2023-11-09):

img directory
====================
This folder should contain the images for the product documentation

## General Images
* `sfe_logo_sm.png` - SparkFun flame logo (Cover page for with-pdf extension)
* `sfe_logo_sq.png` - SparkFun flame logo (favicon)

## Directory
* `qr_code` - QR codes for the product documentation

### QR Codes
* [QR code generator](https://qrgenerator.org/)
    * Flame Color: #E0311D
    * Frame Color: #3C464D
* [Remove meta data from svg](https://jakearchibald.github.io/svgomg/)

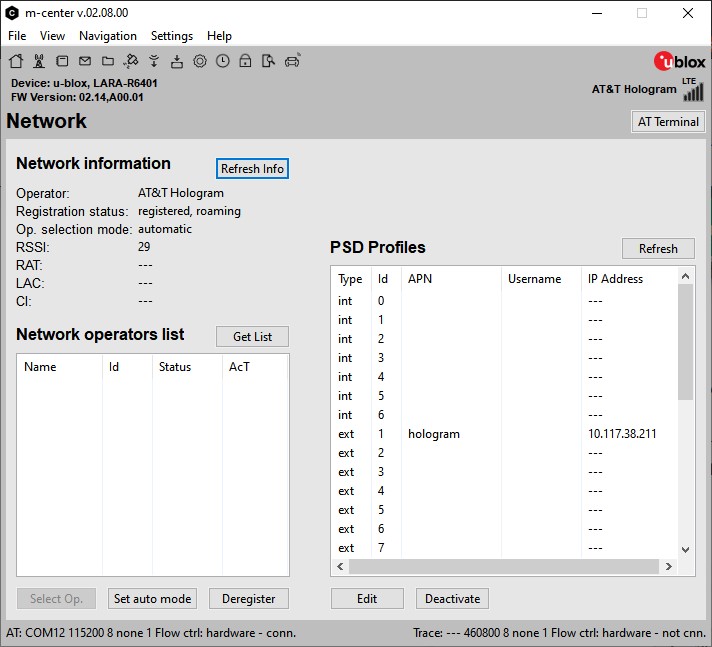
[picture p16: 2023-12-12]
docs/assets/img/m-center_network.jpg

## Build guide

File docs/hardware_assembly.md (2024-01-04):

---
icon: material/tools
---

## Basic Assembly

The fastest way to get up and running with the LTE Stick is by connecting it to a computer through the USB-C connector and then using u-blox's mcenter software. 

<figure markdown>
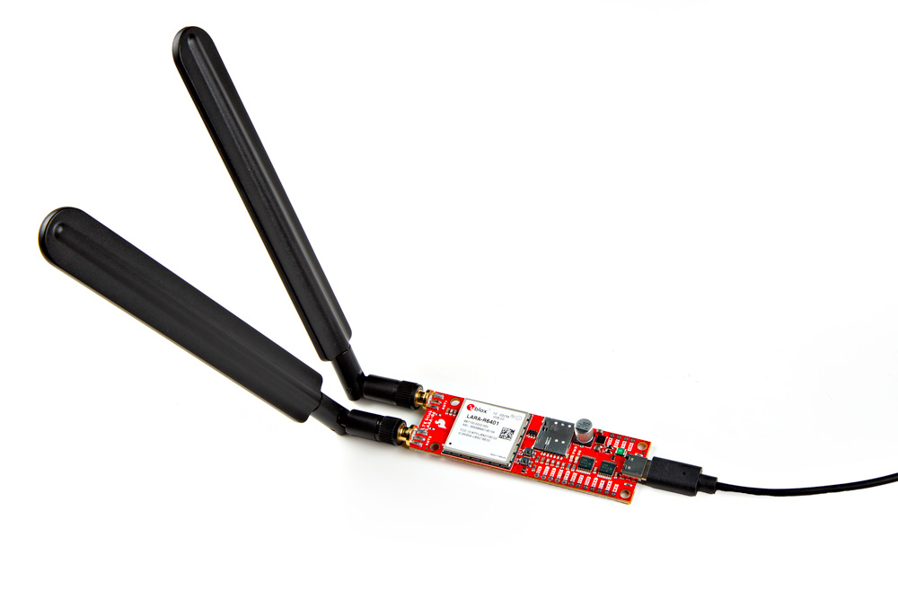
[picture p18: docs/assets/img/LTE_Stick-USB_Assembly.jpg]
Basic USB-C assembly of the LTE Stick

</figure>

## Soldered Assembly

??? note "New to soldering?"
	If you have never soldered before or need a quick refresher, check out our [How to Solder: Through-Hole Soldering](https://learn.sparkfun.com/tutorials/how-to-solder-through-hole-soldering) guide.
	<p align="center">
		<a href="https://learn.sparkfun.com/tutorials/5">
		Tutorial's thumbnail<br>
        How to Solder: Through-Hole Soldering</a>
	</p>

We specifically designed this board to fit on a breadboard with headers soldered to it for easy prototype circuit building with the LARA-R6. This assembly is strongly recommended for those who wish to use the LTE Stick with the SparkFun u-blox Cellular Library to make connections between the LTE Stick, microcontroller, and other hardware (where necessary).

!!! note
    This assembly assumes the use of the [SparkFun Thing Plus - ESP32 WROOM (USB-C)](https://www.sparkfun.com/products/20168) to make serial connections between the boards. If you are using a different microcontroller, adjust the serial connections between the two boards to the appropriate pins.

Start by soldering [male headers](https://www.sparkfun.com/products/116) to both sets of PTH pins on either side of the board. Next, connect the TXD and RXD pins on the LTE Stick to the Serial1 pins on the Thing Plus - ESP32 (USB-C). Finally, connect VUSB on the Thing Plus to VIN on the LTE Stick and connect the ground pins on both boards to each other. With everything wired up, your completed assembly should resemble the photo below:

<figure markdown>
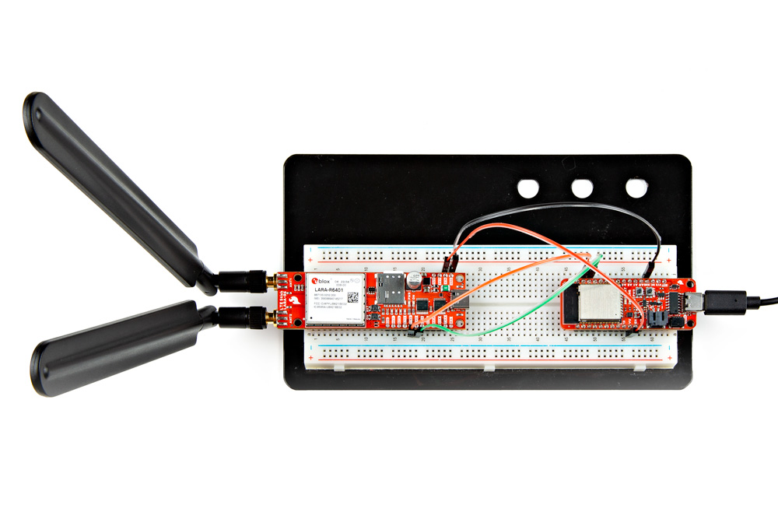
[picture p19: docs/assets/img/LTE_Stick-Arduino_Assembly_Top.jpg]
Completed soldered assembly with serial connection between the LTE Stick to Thing Plus ESP32

<figcaption><i>Having trouble seeing the connections in detail? Click on the image for a larger view.</i></figcaption>
</figure>

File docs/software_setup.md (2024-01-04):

---
icon: simple/arduino
---

## Arduino IDE

Most users may already be familiar with the Arduino IDE and its use. However, for those of you who have never heard the name *Arduino* before, feel free to check out the [Arduino website](https://www.arduino.cc/en/Guide/HomePage). To get started with using the Arduino IDE, check out our tutorials below:

<div class="grid cards" markdown align="center">

-   <a href="https://learn.sparkfun.com/tutorials/61">
	<figure markdown>
	Installing the Arduino IDE
	</figure>

    ---
        
    **Installing the Arduino IDE**</a>

-   <a href="https://learn.sparkfun.com/tutorials/15">
    Installing an Arduino Library
	</figure>
    
    ---
    
    **Installing an Arduino Library**</a>

-   <a href="https://learn.sparkfun.com/tutorials/1265">
    <figure markdown>
	Installing Board Definitions in the Arduino IDE
	</figure>
    
    ---
    
    **Installing Board Definitions in the Arduino IDE**</a>

</div>

## SparkFun u-blox Cellular Arduino Library

The SparkFun u-blox Cellular Arduino Library is a generic AT command-set library that works with multiple u-blox cellular modules that share the same [AT Command Set](). This includes the LARA-R6 on this board as well as the SARA-R5 and others. Most of the examples are generic and work with all modules but some require selecting a specific module to function properly.

Download the library through the Arduino Library Manager tool by searching for <b>"SparkFun u-blox Cellular"</b> and download the latest version. Users who prefer to install it manually can download it from the [GitHub repository](https://github.com/sparkfun/SparkFun_u-blox_Cellular_Arduino_Library) or by clicking the button below:

<center>
[SparkFun u-blox Cellular Arduino Library (ZIP))](https://github.com/sparkfun/SparkFun_u-blox_Cellular_Arduino_Library/archive/refs/heads/main.zip){ .md-button .md-button--primary }    
</center>

With the library installed, let's move on to taking a closer look at a few of the examples included in it.

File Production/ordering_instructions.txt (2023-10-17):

panel size, 117x186mm
PCB thickness, 1.6mm
number of layers, 4
controlled impedance, JLC7628
material, TG155
soldermask color, Red
silkscreen color, White
oz copper, 1oz
finish, HASL lead free
stencils, top
pcs per panel, 8
min trace width, 0.2393mm / 0.0094in
min drill size, 0.3048mm / 0.0120in
filename to layer stackup 1/2/3/4: GTL, GL2, GL3, GBL

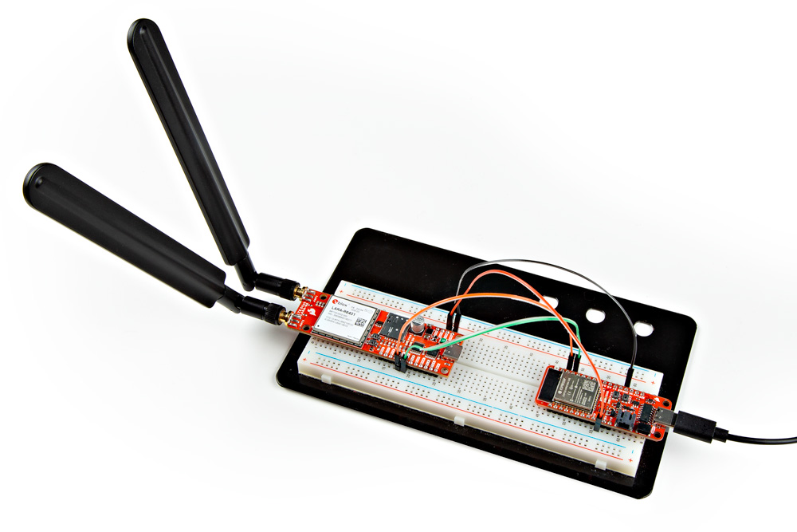
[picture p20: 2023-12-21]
docs/assets/img/LTE_Stick-Arduino_Assembly.jpg

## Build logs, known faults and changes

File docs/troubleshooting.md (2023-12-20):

## Arduino Library Serial Selection

All examples in the [SparkFun u-blox Cellular Arduino Library](https://github.com/sparkfun/SparkFun_u-blox_Cellular_Arduino_Library) default to use <code>Serial1</code> for serial communication between the LTE Stick and microcontroller. If your selected microcontroller does not have this serial port, adjust this line to the correct serial port name:

```c++
#define mySerial Serial1
```

Otherwise, you can set up Software Serial by uncommenting the following line and, if necessary, adjusting the pins set for software serial (RX/TX) depending on the [software serial library limitations](https://docs.arduino.cc/learn/built-in-libraries/software-serial).

```c++
// SoftwareSerial mySerial(16, 17);
```

## Test Point Cluster Precautions

Reminder, all the test point clusters on the back of the board (UART2, I<sup>2</sup>C, and GPIO) are <i>not</i> level shifted and run at <b>1.8V</b>. Also note these are directly connected to the LARA-R6 and may be damaged by ESD shocks beyond the LARA-R6's ESD rating.

## General Troubleshooting

!!! info
    <p><span class="glyphicon glyphicon-question-sign" aria-hidden="true"></span> <strong>Not working as expected and need help? </strong></p>
    <p>If you need technical assistance and more information on a product that is not working as you expected, we recommend heading on over to the <a href="https://www.sparkfun.com/technical_assistance">SparkFun Technical Assistance</a> page for some initial troubleshooting.</p>
    <center>
    [SparkFun Technical Assistance Page](https://www.sparkfun.com/technical_assistance){ .md-button .md-button--primary }
    </center>
    <p>If you can't find what you need there, you'll need a <a href="https://forum.sparkfun.com/ucp.php?mode=register">Forum Account</a> to search product forums and post questions.<p>

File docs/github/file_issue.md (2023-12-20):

# Did we make a mistake?

Spot something wrong? Please let us know. 

<!-- Technical Assistance Box -->
!!! warning "Need Help?"
    If you need technical assistance or more information on a product that is not working as you expected, we recommend heading on over to the [SparkFun Technical Assistance](https://www.sparkfun.com/technical_assistanc) page for some initial troubleshooting. This **Submit Issues** page is not where users should seek assistance.

    <center>
    [SparkFun Technical Assistance Page](https://www.sparkfun.com/technical_assistance){ .md-button .md-button--primary }
    </center>
    
    If you can't find what you need there, the [SparkFun Forums](https://forum.sparkfun.com/index.php) is a great place to search the product forums and ask questions.
    
    !!! info "Account Registration Required"
        For your first visit to our forum, you'll need to create a [Forum Account](https://forum.sparkfun.com/ucp.php?mode=register) to post questions.

## Discrepancies in the Documentation

All of our documentation can be modified by you! Please help us make it better.

* The documentation files for these pages are contained in the [`docs` folder](https://github.com/sparkfun/SparkFun_LTE_Stick_LARA_R6/tree/main/docs) of the [SparkFun LTE Stick - LARA-R6 repository](https://github.com/sparkfun/SparkFun_LTE_Stick_LARA_R6).

### 🔍 Spot something wrong?

If a section of the documentation is incorrect, please [open an issue](https://github.com/sparkfun/SparkFun_LTE_Stick_LARA_R6/issues) and let us know.

### Do you have a suggested correction?

1. With a GitHub account, [fork this repository](https://github.com/sparkfun/SparkFun_LTE_Stick_LARA_R6/fork).
2. Add your correction(s) or improvement(s) to the markdown file(s)
3. File a pull request with your changes, and enjoy making the ~~words~~ ~~worlds~~ world a better place.
	* Once received, the documentation specialist will automatically be notified.
	* We will review your suggested improvement(s) to make sure they are correct and fit within our documentation standards.

## Problems in the Hardware Design

All of our designs are open-source! Please help us make it better.

* Our board design files are contained in the [`Hardware` folder](https://github.com/sparkfun/SparkFun_LTE_Stick_LARA_R6/tree/main/Hardware) of the [SparkFun LTE Stick - LARA-R6 repository](https://github.com/sparkfun/SparkFun_LTE_Stick_LARA_R6).

### Does something not make sense? 🤔

If part of the design is confusing, please [open an issue](https://github.com/sparkfun/SparkFun_LTE_Stick_LARA_R6/issues) and let us know.

### Did we forget to include an important function of the board? 🤦

If part of the board's functionality is missing, please [open an issue](https://github.com/sparkfun/SparkFun_LTE_Stick_LARA_R6/issues) and file a feature request.

!!! tip "Design Considerations"
	Please keep in mind that we may intentionally exclude certain functions of the board to meet our product design requirements.
	
	* *For example, our Qwiic Micro boards are intended to fit on a small board layout and only use I<sup>2</sup>C communication; therefore, we may not have the SPI and interrupt pins available for users.*

### Do you wish to contribute directly to improving the board design?

1. With a GitHub account, [fork this repository](https://github.com/sparkfun/SparkFun_LTE_Stick_LARA_R6/fork).
2. Add your design augmentation(s)
3. File a pull request with your changes, and enjoy making the ~~words~~ ~~worlds~~ world a better place.
	1. Once received, the engineer in charge of the original design will automatically be notified.
	2. We will review your suggested improvement(s) to verify that they are within our board design standards and meet our product design requirements.
	3. If approved, we will flag these changes for our next board revision. Congrats! 🍻

		!!! info
			Even if your suggestion is accepted, these changes may not be immediately available for purchase. We may have to cycle through our current product inventory first.

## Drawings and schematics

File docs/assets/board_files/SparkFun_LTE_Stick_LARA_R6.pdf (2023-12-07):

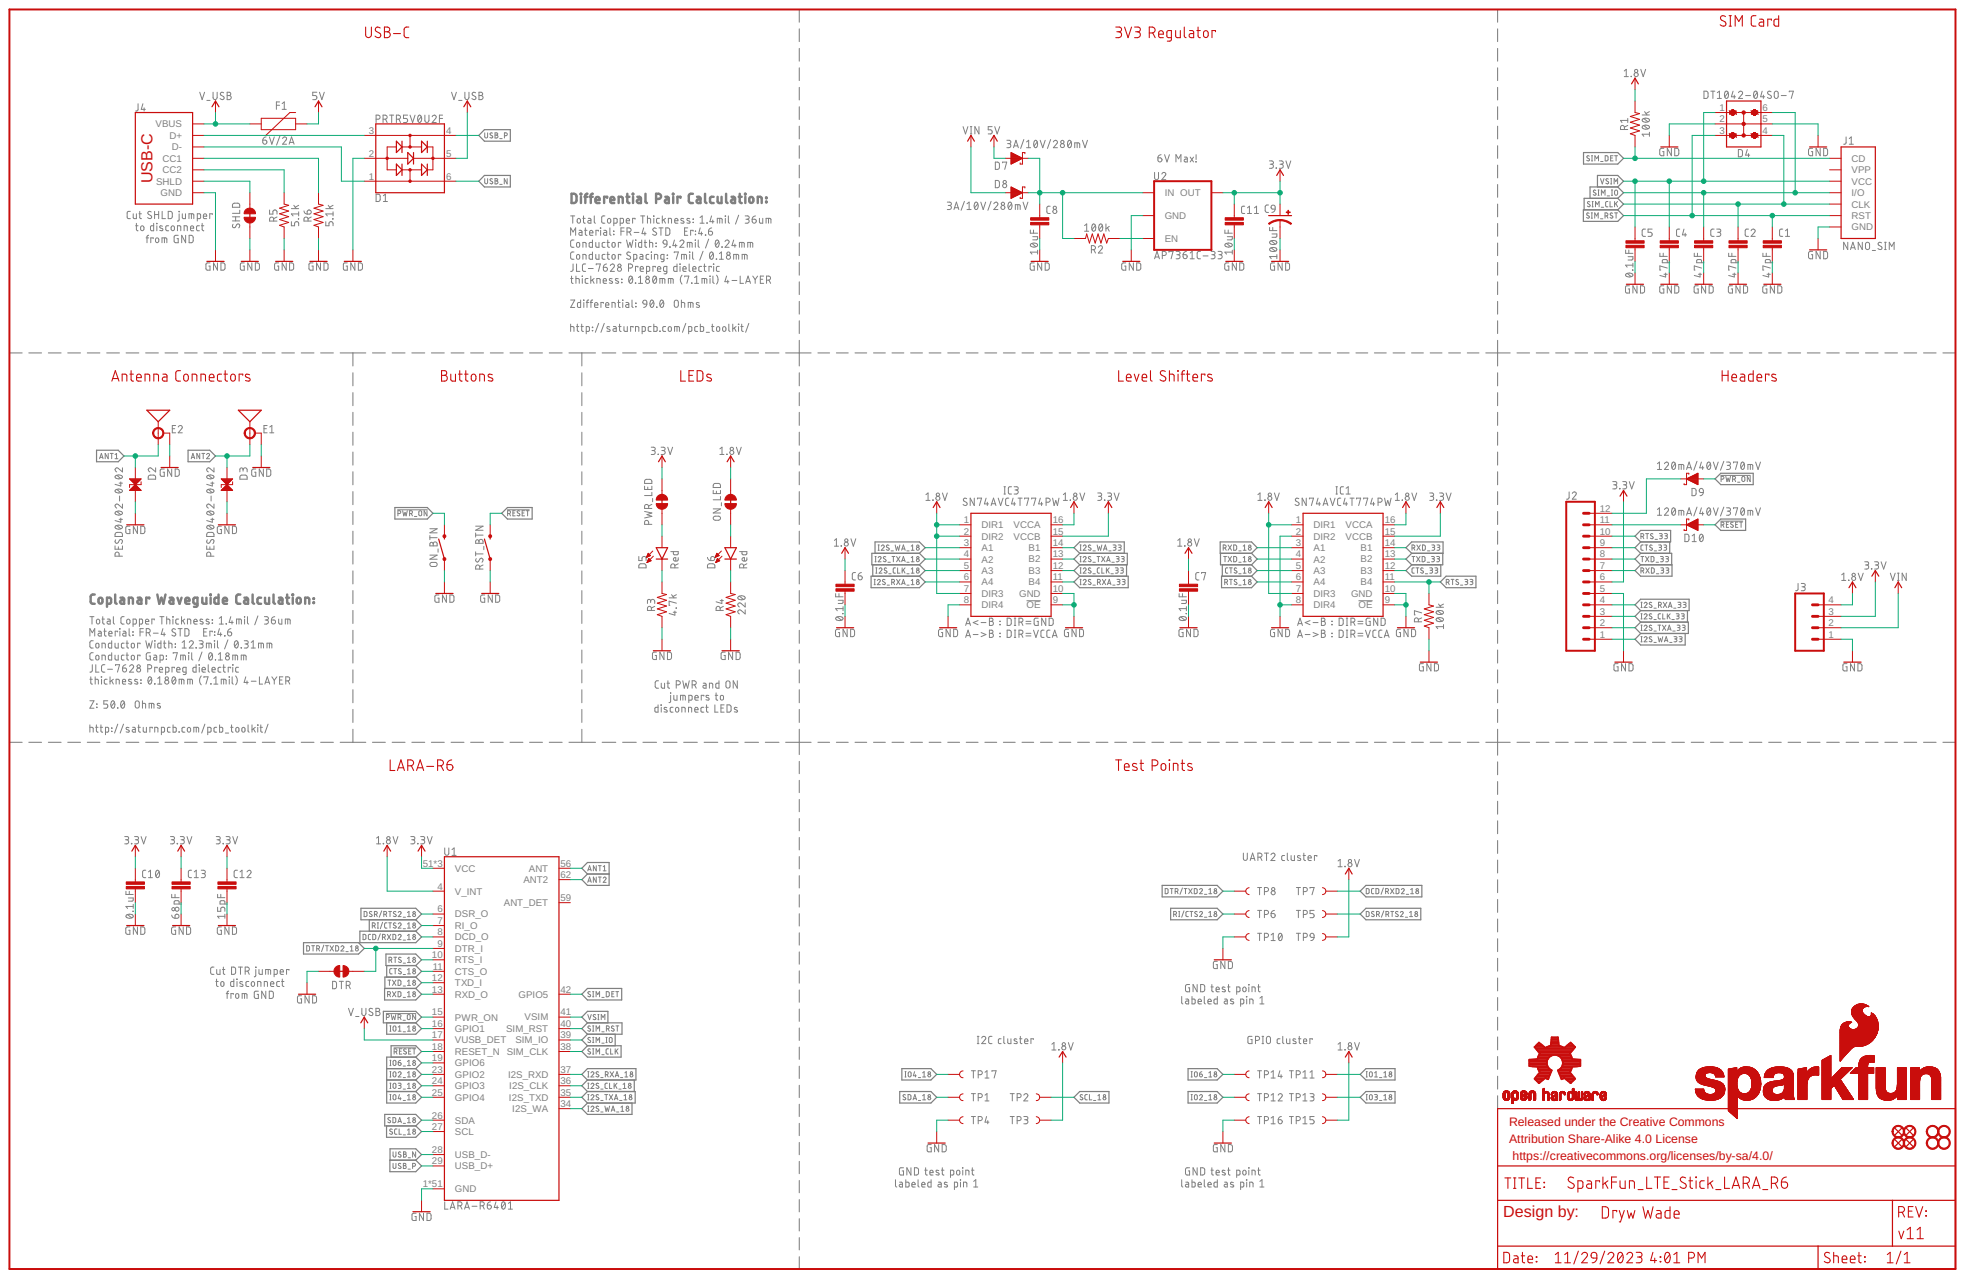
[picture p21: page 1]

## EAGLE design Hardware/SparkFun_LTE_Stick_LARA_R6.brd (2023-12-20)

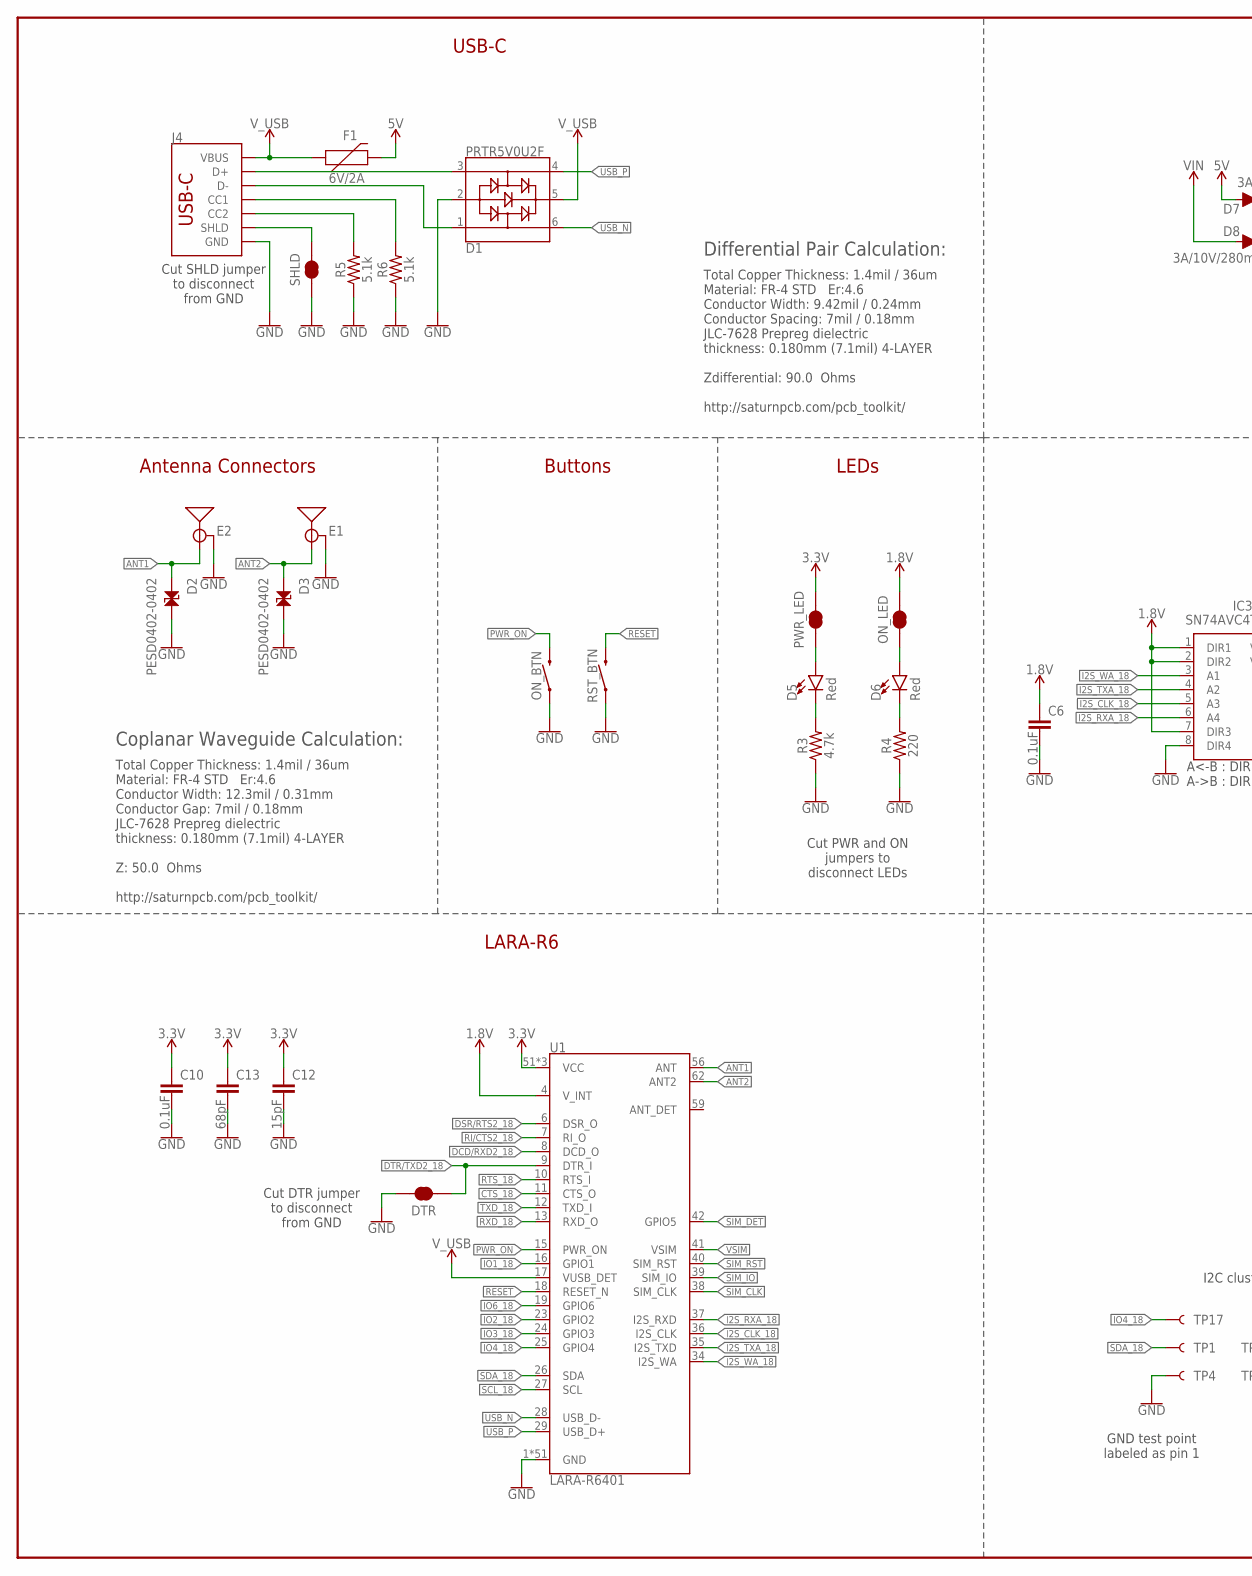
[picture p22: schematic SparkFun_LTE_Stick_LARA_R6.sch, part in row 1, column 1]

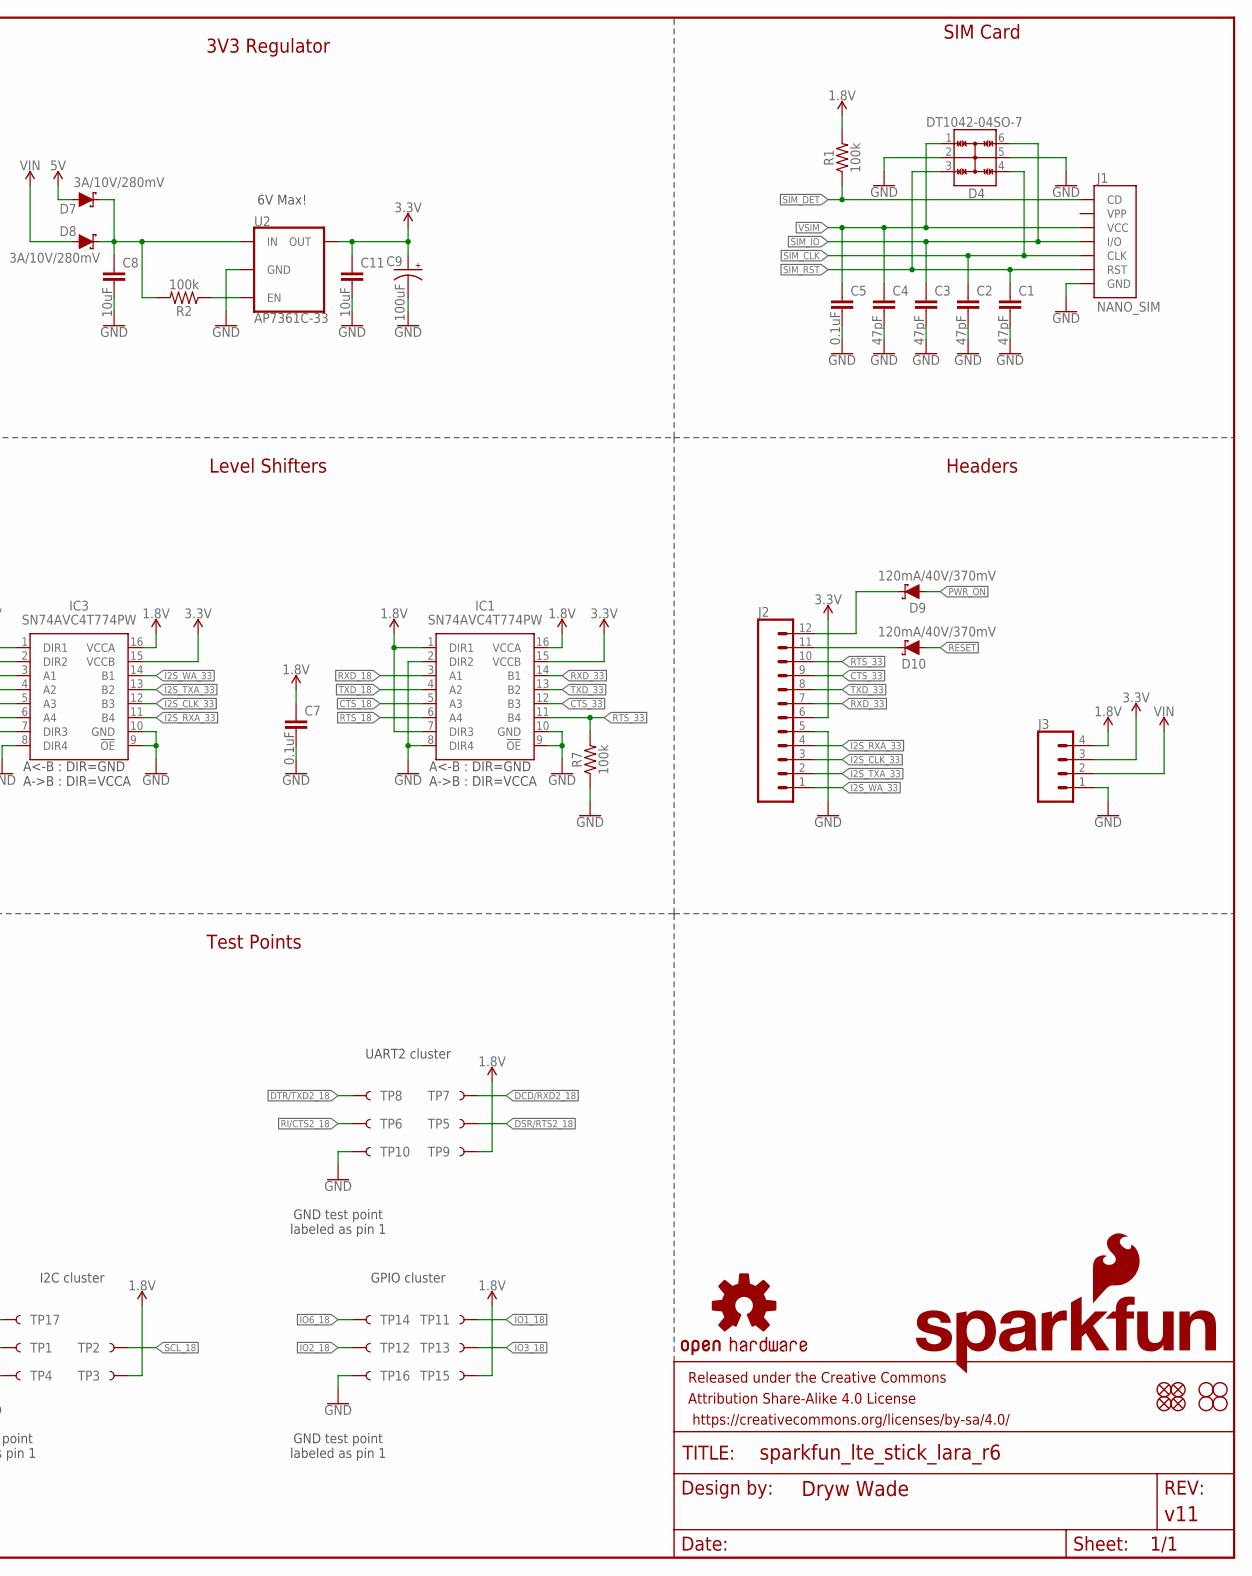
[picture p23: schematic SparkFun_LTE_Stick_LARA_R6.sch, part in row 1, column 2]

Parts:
C1, C2, C3, C4: 47pF; 0603
C5, C6, C7, C10: 0.1uF; 0603
C8, C11: 10uF; 0805
C9: 100uF; PANASONIC_D
C12: 15pF; 0603
C13: 68pF; 0603
D1: PRTR5V0U2F; SOT886
D2, D3: PESD0402-0402; 0402
D4: DT1042-04SO-7; SOT23-6L
D5, D6: Red; LED-0603
D7, D8: 3A/10V/280mV; SOD-323
D9, D10: 120mA/40V/370mV; SOD-523
DTR: JUMPER-SMT_2_NC_TRACE_SILK; SMT-JUMPER_2_NC_TRACE_SILK
E1, E2: ANTENNA-SMA-GROUNDEDEDGE_SMA; SMA-EDGE
F1: 6V/2A; 1210
FD1, FD2, FD3, FD4: FIDUCIAL1X2; FIDUCIAL-1X2
FRAME1: FRAME-LEDGER; CREATIVE_COMMONS
H1, H2, H3, H4: STAND-OFF
IC1, IC3: SN74AVC4T774PW; SOP65P640X120-16N
J1: NANO_SIM; NANO_SIM_PP
J2: CONN_12NO_SILK; 1X12_NO_SILK
J3: CONN_041X04_NO_SILK_NO_POP; 1X04_NO_SILK
J4: USB_C_4-LAYER_PADS; USB-C-16P_4LAYER-PADS
LOGO1: SFE_LOGO_NAME_FLAME.1_INCH; SFE_LOGO_NAME_FLAME_.1
LOGO2: OSHW-LOGOM; OSHW-LOGO-M
ON_BTN: MOMENTARY-SWITCH-SPST-SMD-4.6X2.8MM; TACTILE_SWITCH_SMD_4.6X2.8MM
ON_LED: JUMPER-SMT_2_NC_TRACE_SILK; SMT-JUMPER_2_NC_TRACE_SILK
PWR_LED: JUMPER-SMT_2_NC_TRACE_SILK; SMT-JUMPER_2_NC_TRACE_SILK
R1, R2, R7: 100k; 0603
R3: 4.7k; 0603
R4: 220; 0603
R5, R6: 5.1k; 0603
RST_BTN: MOMENTARY-SWITCH-SPST-SMD-4.6X2.8MM; TACTILE_SWITCH_SMD_4.6X2.8MM
SHLD: JUMPER-SMT_2_NC_TRACE_SILK; SMT-JUMPER_2_NC_TRACE_SILK
TP1, TP2, TP3, TP4, TP5, TP6, TP7, TP8, TP9, TP10, TP11, TP12, TP13, TP14, TP15, TP16, TP17: TEST-POINT3X5; PAD.03X.05
U1: LARA-R6401; LARA-LGA
U2: AP7361C-33; UDFN-8

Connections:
1.8V: C6.1, C7.1, IC1.1 (DIR1), IC1.7 (DIR3), IC1.16 (VCCA), IC3.1 (DIR1), IC3.2 (DIR2), IC3.7 (DIR3), IC3.16 (VCCA), J3.4, ON_LED.2, R1.2, TP3.1, TP9.1, TP15.1, U1.4 (V_INT)
3.3V: C9.+, C10.1, C11.1, C12.1, C13.1, IC1.15 (VCCB), IC3.15 (VCCB), J2.6, J3.3, PWR_LED.2, U1.51 (VCC), U1.52 (VCC), U1.53 (VCC), U2.1 (OUT)
5V: D7.A, F1.2
!PWR_ON!: D9.A, ON_BTN.3 (2), ON_BTN.4 (2), U1.15 (PWR_ON)
!RESET!: D10.A, RST_BTN.3 (2), RST_BTN.4 (2), U1.18 (RESET_N)
ANT1: D2.1, E2.SIG (SIGNAL), U1.56 (ANT)
ANT2: D3.1, E1.SIG (SIGNAL), U1.62 (ANT2)
CTS_18: IC1.5 (A3), U1.11 (CTS_O)
CTS_33: IC1.12 (B3), J2.9
DCD/RXD2_18: TP7.1, U1.8 (DCD_O)
DSR/RTS2_18: TP5.1, U1.6 (DSR_O)
DTR/TXD2_18: DTR.2, TP8.1, U1.9 (DTR_I)
EN: R2.1, U2.5 (EN)
GND: C1.2, C2.2, C3.2, C4.2, C5.2, C6.2, C7.2, C8.2, C9.-, C10.2, C11.2, C12.2, C13.2, D1.2, D2.2, D3.2, D4.2, D4.5, DTR.1, E1.GND@0 (GND), E1.GND@1 (GND), E1.GND@2 (GND), E1.GND@3 (GND), E2.GND@0 (GND), E2.GND@1 (GND), E2.GND@2 (GND), E2.GND@3 (GND), IC1.2 (DIR2), IC1.8 (DIR4), IC1.9 (!OE), IC1.10 (GND), IC3.8 (DIR4), IC3.9 (!OE), IC3.10 (GND), J1.A1 (GND), J1.A2 (GND), J1.A3 (GND), J1.A4 (GND), J1.C5 (GND), J2.5, J3.1, J4.GND, J4.GND2 (GND), ON_BTN.1, ON_BTN.2 (1), R3.1, R4.1, R5.1, R6.1, R7.1, RST_BTN.1, RST_BTN.2 (1), SHLD.1, TP4.1, TP10.1, TP16.1, U1.1 (GND), U1.3 (GND), U1.5 (GND), U1.14 (GND), U1.20 (GND), U1.21 (GND), U1.22 (GND), U1.30 (GND), U1.32 (GND), U1.43 (GND), U1.50 (GND), U1.54 (GND), U1.55 (GND), U1.57 (GND), U1.58 (GND), U1.60 (GND), U1.61 (GND), U1.63 (GND), U1.64 (GND), U1.65 (GND), U1.66 (GND), U1.67 (GND), U1.68 (GND), U1.69 (GND), U1.70 (GND), U1.71 (GND), U1.72 (GND), U1.73 (GND), U1.74 (GND), U1.75 (GND), U1.76 (GND), U1.77 (GND), U1.78 (GND), U1.79 (GND), U1.80 (GND), U1.81 (GND), U1.82 (GND), U1.83 (GND), U1.84 (GND), U1.85 (GND), U1.86 (GND), U1.87 (GND), U1.88 (GND), U1.89 (GND), U1.90 (GND), U1.91 (GND), U1.92 (GND), U1.93 (GND), U1.94 (GND), U1.95 (GND), U1.96 (GND), U2.4 (GND), U2.EP (GND)
I2S_CLK_18: IC3.5 (A3), U1.36 (I2S_CLK)
I2S_CLK_33: IC3.12 (B3), J2.3
I2S_RXA_18: IC3.6 (A4), U1.37 (I2S_RXD)
I2S_RXA_33: IC3.11 (B4), J2.4
I2S_TXA_18: IC3.4 (A2), U1.35 (I2S_TXD)
I2S_TXA_33: IC3.13 (B2), J2.2
I2S_WA_18: IC3.3 (A1), U1.34 (I2S_WA)
I2S_WA_33: IC3.14 (B1), J2.1
IO1_18: TP11.1, U1.16 (GPIO1)
IO2_18: TP12.1, U1.23 (GPIO2)
IO3_18: TP13.1, U1.24 (GPIO3)
IO4_18: TP17.1, U1.25 (GPIO4)
IO6_18: TP14.1, U1.19 (GPIO6)
unnamed: D5.C, R3.2
unnamed: D5.A, PWR_LED.1
unnamed: D6.A, ON_LED.1
unnamed: D6.C, R4.2
unnamed: D10.C, J2.11
unnamed: D9.C, J2.12
unnamed: C8.1, D7.C, D8.C, R2.2, U2.8 (IN)
unnamed: J4.B5 (CC2), R5.2
unnamed: J4.A5 (CC1), R6.2
unnamed: D1.3, J4.A6 (D+), J4.B6 (D+)
unnamed: D1.1, J4.A7 (D-), J4.B7 (D-)
RI/CTS2_18: TP6.1, U1.7 (RI_O)
RTS_18: IC1.6 (A4), U1.10 (RTS_I)
RTS_33: IC1.11 (B4), J2.10, R7.2
RXD_18: IC1.3 (A1), U1.13 (RXD_O)
RXD_33: IC1.14 (B1), J2.7
SCL_18: TP2.1, U1.27 (SCL)
SDA_18: TP1.1, U1.26 (SDA)
SHLD: J4.SHLD1 (SHLD), J4.SHLD2 (SHLD), J4.SHLD3 (SHLD), J4.SHLD4 (SHLD), SHLD.2
SIM_CLK: C2.1, D4.4, J1.C3 (CLK), U1.38 (SIM_CLK)
SIM_DET: J1.CD, R1.1, U1.42 (GPIO5)
SIM_IO: C3.1, D4.6, J1.C7 (I/O), U1.39 (SIM_IO)
SIM_RST: C1.1, D4.3, J1.C2 (RST), U1.40 (SIM_RST)
TXD_18: IC1.4 (A2), U1.12 (TXD_I)
TXD_33: IC1.13 (B2), J2.8
USB_N: D1.6, U1.28 (USB_D-)
USB_P: D1.4, U1.29 (USB_D+)
VIN: D8.A, J3.2
VSIM: C4.1, C5.1, D4.1, J1.C1 (VCC), U1.41 (VSIM)
V_USB: D1.5, F1.1, J4.VBUS1 (VBUS), J4.VBUS2 (VBUS), U1.17 (VUSB_DET)

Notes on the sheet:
USB-C
LARA-R6
Test Points
Headers
3V3 Regulator
SIM Card
Antenna Connectors
Level Shifters
Buttons
LEDs
Cut PWR and ON jumpers to disconnect LEDs
Cut SHLD jumper to disconnect from GND
Cut DTR jumper to disconnect from GND
6V Max!
GND test point labeled as pin 1
I2C cluster
GPIO cluster
UART2 cluster
Differential Pair Calculation:
Total Copper Thickness: 1.4mil / 36um Material: FR-4 STD Er:4.6 Conductor Width: 9.42mil / 0.24mm Conductor Spacing: 7mil / 0.18mm JLC-7628 Prepreg dielectric thickness: 0.180mm (7.1mil) 4-LAYER Zdifferential: 90.0 Ohms http://saturnpcb.com/pcb_toolkit/
Coplanar Waveguide Calculation:
Total Copper Thickness: 1.4mil / 36um Material: FR-4 STD Er:4.6 Conductor Width: 12.3mil / 0.31mm Conductor Gap: 7mil / 0.18mm JLC-7628 Prepreg dielectric thickness: 0.180mm (7.1mil) 4-LAYER Z: 50.0 Ohms http://saturnpcb.com/pcb_toolkit/

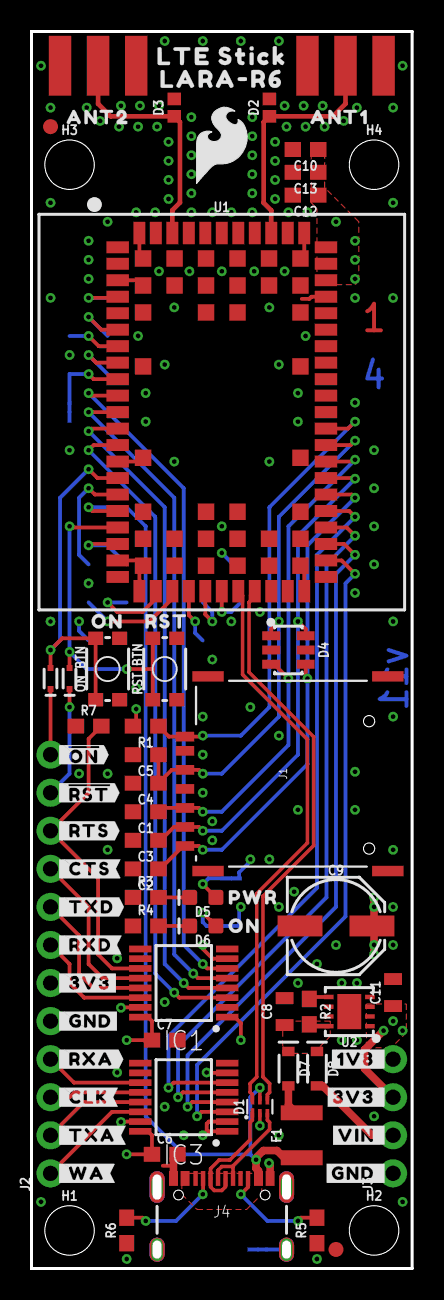
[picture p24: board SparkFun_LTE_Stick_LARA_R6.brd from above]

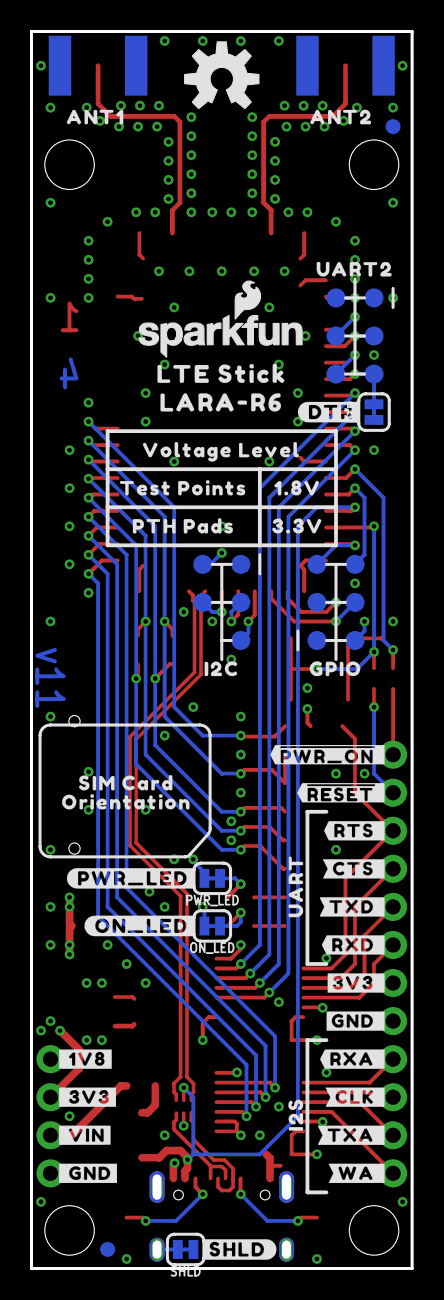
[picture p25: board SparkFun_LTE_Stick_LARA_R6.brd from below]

Board: 4 copper layers, 25.4 x 82.5 mm, 137 parts (61 on the bottom side), 57 nets.

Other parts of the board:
U$1, U$25: LTE_STICK0
U$2: SFE_LOGO_FLAME_.2
U$3, U$15: #_3V3#0
U$4, U$5: #_GND#0
U$6: #SHLD#0
U$7, U$8: #GND_#0
U$9, U$12: #3V3_#0
U$10: #DTR#0
U$11: #VIN_#0
U$13: #1V8_#0
U$14: #_1V8#0
U$16: #_VIN#0
U$17: #_CTS#0
U$18: #_RTS#0
U$19: #RXD_#0
U$20: #TXD_#0
U$21: #_CLK#0
U$22: #_WA#0
U$23: #RXA_#0
U$24: #TXA_#0
U$26: SIM_CARD0
U$27: VOLTAGE_LEVEL0
U$28: PWR0
U$29, U$36: ANT10
U$30: TEST_POINTS0
U$31, U$35: LARA#R60
U$32: #_RXA#0
U$33: #_#RST##0
U$34: PTH_PADS0
U$37, U$39: ON0
U$38: ##PWR_ON#_#0
U$40: #_TXA#0
U$41: #_TXD#0
U$42: #_RXD#0
U$43: #CLK_#0
U$44: #WA_#0
U$45: #RTS_#0
U$46: #CTS_#0
U$47: ##RESET#_#0
U$48: UART0
U$49: I2S0
U$50: 1#8V0
U$51: ORIENTATION0
U$52: RST0
U$53: #ON_LED#0
U$54: 3#3V0
U$55: ORDERING_INSTRUCTIONS
U$56: UART20
U$57: GPIO0
U$58: I2C0
U$59: #_#ON##0
U$60: #PWR_LED#0
U$61, U$62: ANT20

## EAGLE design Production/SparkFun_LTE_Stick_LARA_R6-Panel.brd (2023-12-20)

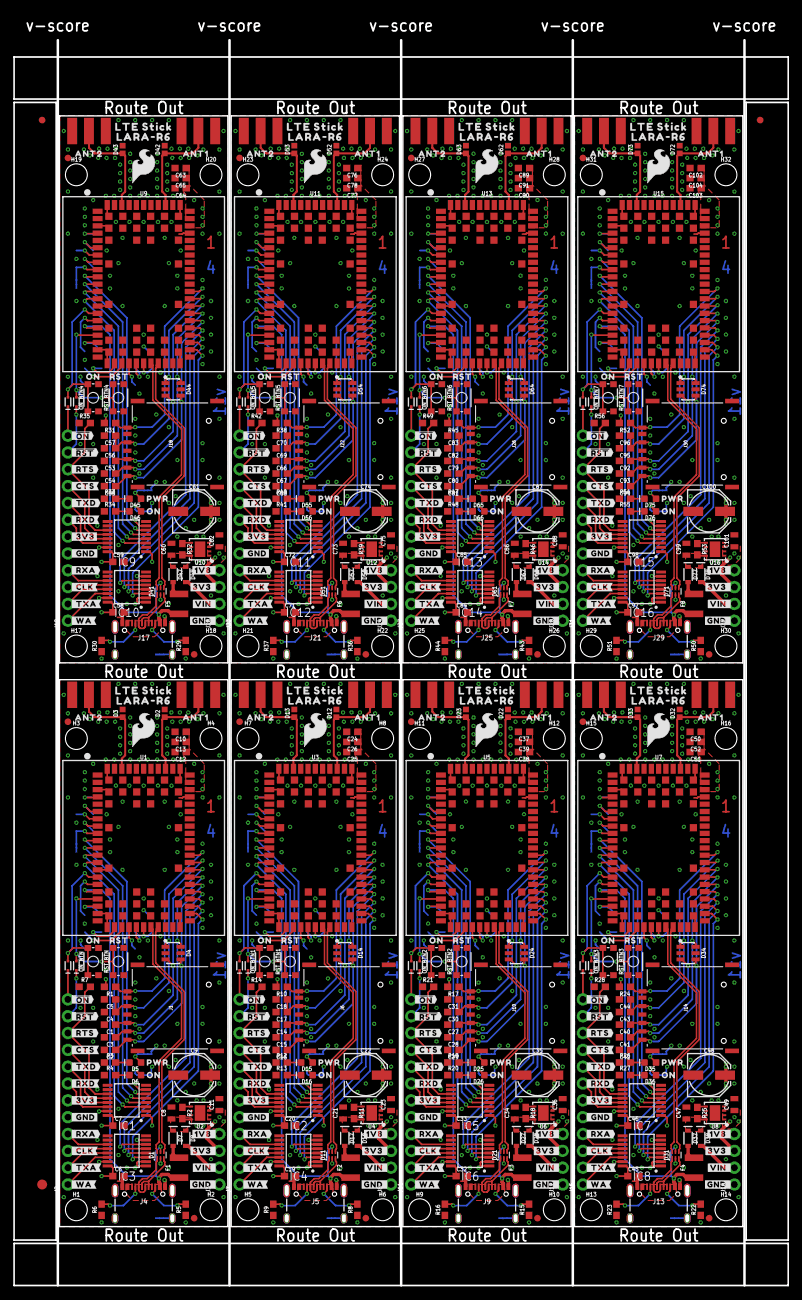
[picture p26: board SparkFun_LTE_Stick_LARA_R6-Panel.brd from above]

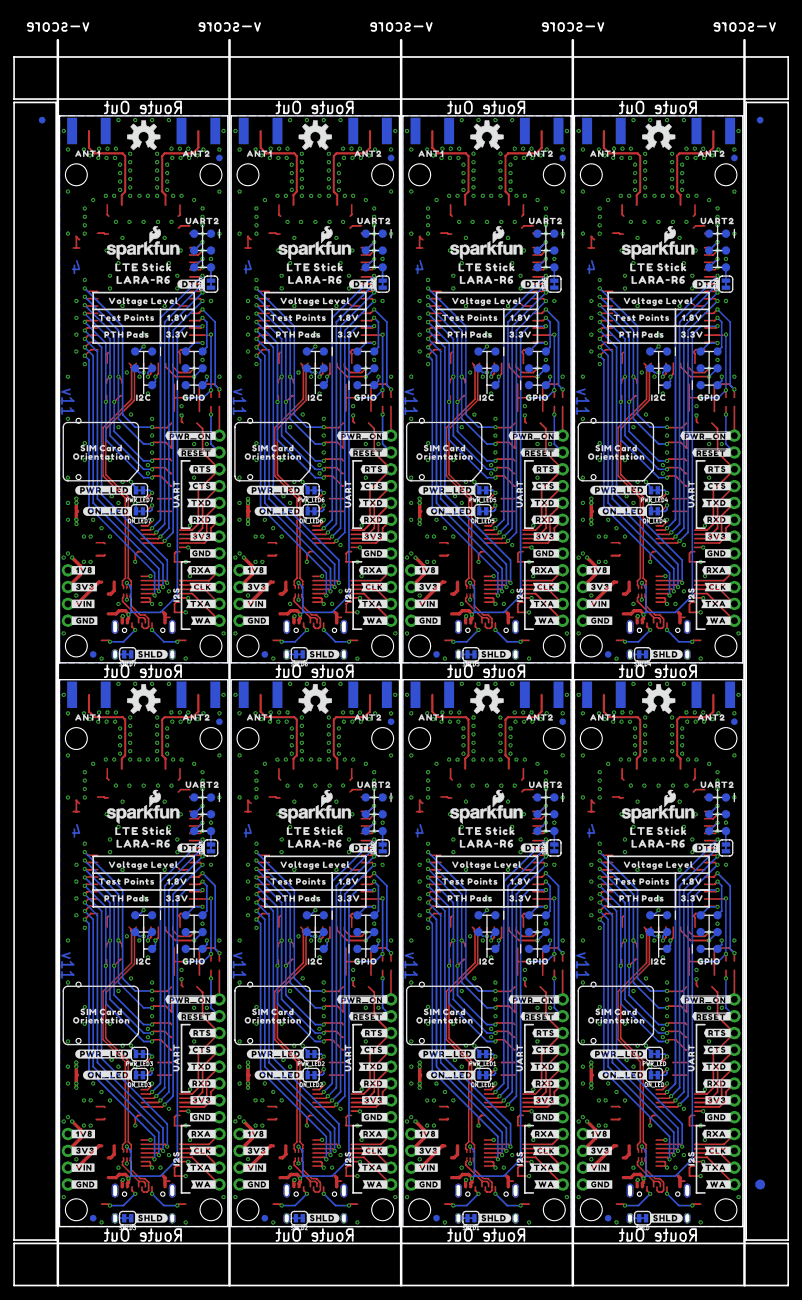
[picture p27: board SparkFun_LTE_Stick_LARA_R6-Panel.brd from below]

Board: 4 copper layers, 116.8 x 188.0 mm, 1086 parts (491 on the bottom side), 456 nets.

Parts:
C1, C2, C3, C4, C14, C15, C16, C17, C27, C28, C29, C30, C40, C41, C42, C43, C53, C54, C55, C56, C66, C67, C68, C69, C79, C80, C81, C82, C92, C93, C94, C95: 47pF; 0603
C5, C6, C7, C10, C18, C19, C20, C24, C31, C32, C33, C37, C44, C45, C46, C50, C57, C58, C59, C63, C70, C71, C72, C76, C83, C84, C85, C89, C96, C97, C98, C102: 0.1uF; 0603
C8, C11, C21, C23, C34, C36, C47, C49, C60, C62, C73, C75, C86, C88, C99, C101: 10uF; 0805
C9, C22, C35, C48, C61, C74, C87, C100: 100uF; PANASONIC_D
C12, C25, C38, C51, C64, C77, C90, C103: 15pF; 0603
C13, C26, C39, C52, C65, C78, C91, C104: 68pF; 0603
D1, D11, D21, D31, D41, D51, D61, D71: PRTR5V0U2F; SOT886
D2, D3, D12, D13, D22, D23, D32, D33, D42, D43, D52, D53, D62, D63, D72, D73: PESD0402-0402; 0402
D4, D14, D24, D34, D44, D54, D64, D74: DT1042-04SO-7; SOT23-6L
D5, D6, D15, D16, D25, D26, D35, D36, D45, D46, D55, D56, D65, D66, D75, D76: Red; LED-0603
D7, D8, D17, D18, D27, D28, D37, D38, D47, D48, D57, D58, D67, D68, D77, D78: 3A/10V/280mV; SOD-323
D9, D10, D19, D20, D29, D30, D39, D40, D49, D50, D59, D60, D69, D70, D79, D80: 120mA/40V/370mV; SOD-523
DTR, DTR1, DTR2, DTR3, DTR4, DTR5, DTR6, DTR7: JUMPER-SMT_2_NC_TRACE_SILK; SMT-JUMPER_2_NC_TRACE_SILK
E1, E2, E3, E4, E5, E6, E7, E8, E9, E10, E11, E12, E13, E14, E15, E16: ANTENNA-SMA-GROUNDEDEDGE_SMA; SMA-EDGE
E$1, E$2, E$3, E$4: FIDUCIAL-1X2
E$5, E$6: FIDUCIAL-1.5X3
F1, F2, F3, F4, F5, F6, F7, F8: 6V/2A; 1210
FD1, FD2, FD3, FD4, FD5, FD6, FD7, FD8, FD9, FD10, FD11, FD12, FD13, FD14, FD15, FD16, FD17, FD18, FD19, FD20, FD21, FD22, FD23, FD24, FD25, FD26, FD27, FD28, FD29, FD30, FD31, FD32: FIDUCIAL1X2; FIDUCIAL-1X2
H1, H2, H3, H4, H5, H6, H7, H8, H9, H10, H11, H12, H13, H14, H15, H16, H17, H18, H19, H20, H21, H22, H23, H24, H25, H26, H27, H28, H29, H30, H31, H32: STAND-OFF
IC1, IC2, IC3, IC4, IC5, IC6, IC7, IC8, IC9, IC10, IC11, IC12, IC13, IC14, IC15, IC16: SN74AVC4T774PW; SOP65P640X120-16N
J1, J6, J10, J14, J18, J22, J26, J30: NANO_SIM; NANO_SIM_PP
J2, J7, J11, J15, J19, J23, J27, J31: 1X12_NO_SILK
J3, J8, J12, J16, J20, J24, J28, J32: 1X04_NO_SILK
J4, J5, J9, J13, J17, J21, J25, J29: USB-C-16P_4LAYER-PADS
LOGO1, LOGO3, LOGO5, LOGO7, LOGO9, LOGO11, LOGO13, LOGO15: SFE_LOGO_NAME_FLAME.1_INCH; SFE_LOGO_NAME_FLAME_.1
LOGO2, LOGO4, LOGO6, LOGO8, LOGO10, LOGO12, LOGO14, LOGO16: OSHW-LOGOM; OSHW-LOGO-M
ON_BTN, ON_BTN1, ON_BTN2, ON_BTN3, ON_BTN4, ON_BTN5, ON_BTN6, ON_BTN7: MOMENTARY-SWITCH-SPST-SMD-4.6X2.8MM; TACTILE_SWITCH_SMD_4.6X2.8MM
ON_LED, ON_LED1, ON_LED2, ON_LED3, ON_LED4, ON_LED5, ON_LED6, ON_LED7: JUMPER-SMT_2_NC_TRACE_SILK; SMT-JUMPER_2_NC_TRACE_SILK
PWR_LED, PWR_LED1, PWR_LED2, PWR_LED3, PWR_LED4, PWR_LED5, PWR_LED6, PWR_LED7: JUMPER-SMT_2_NC_TRACE_SILK; SMT-JUMPER_2_NC_TRACE_SILK
R1, R2, R7, R10, R11, R14, R17, R18, R21, R24, R25, R28, R31, R32, R35, R38, R39, R42, R45, R46, R49, R52, R53, R56: 100k; 0603
R3, R12, R19, R26, R33, R40, R47, R54: 4.7k; 0603
R4, R13, R20, R27, R34, R41, R48, R55: 220; 0603
R5, R6, R8, R9, R15, R16, R22, R23, R29, R30, R36, R37, R43, R44, R50, R51: 5.1k; 0603
RST_BTN, RST_BTN1, RST_BTN2, RST_BTN3, RST_BTN4, RST_BTN5, RST_BTN6, RST_BTN7: MOMENTARY-SWITCH-SPST-SMD-4.6X2.8MM; TACTILE_SWITCH_SMD_4.6X2.8MM
SHLD, SHLD1, SHLD2, SHLD3, SHLD4, SHLD5, SHLD6, SHLD7: JUMPER-SMT_2_NC_TRACE_SILK; SMT-JUMPER_2_NC_TRACE_SILK
TP1, TP2, TP3, TP4, TP5, TP6, TP7, TP8, TP9, TP10, TP11, TP12, TP13, TP14, TP15, TP16, TP17, TP18, TP19, TP20, TP21, TP22, TP23, TP24, TP25, TP26, TP27, TP28, TP29, TP30, TP31, TP32, TP33, TP34, TP35, TP36, TP37, TP38, TP39, TP40, TP41, TP42, TP43, TP44, TP45, TP46, TP47, TP48, TP49, TP50, TP51, TP52, TP53, TP54, TP55, TP56, TP57, TP58, TP59, TP60, TP61, TP62, TP63, TP64, TP65, TP66, TP67, TP68, TP69, TP70, TP71, TP72, TP73, TP74, TP75, TP76, TP77, TP78, TP79, TP80, TP81, TP82, TP83, TP84, TP85, TP86, TP87, TP88, TP89, TP90, TP91, TP92, TP93, TP94, TP95, TP96, TP97, TP98, TP99, TP100, TP101, TP102, TP103, TP104, TP105, TP106, TP107, TP108, TP109, TP110, TP111, TP112, TP113, TP114, TP115, TP116, TP117, TP118, TP119, TP120, TP121, TP122, TP123, TP124, TP125, TP126, TP127, TP128, TP129, TP130, TP131, TP132, TP133, TP134, TP135, TP136: TEST-POINT3X5; PAD.03X.05
U1, U3, U5, U7, U9, U11, U13, U15: LARA-R6401; LARA-LGA
U2, U4, U6, U8, U10, U12, U14, U16: AP7361C-33; UDFN-8
U$1, U$25, U$55, U$79, U$123, U$140, U$184, U$201, U$245, U$262, U$306, U$323, U$367, U$384, U$428, U$445: LTE_STICK0
U$2, U$84, U$145, U$206, U$267, U$328, U$389, U$450: SFE_LOGO_FLAME_.2
U$3, U$15, U$63, U$73, U$124, U$134, U$185, U$195, U$246, U$256, U$307, U$317, U$368, U$378, U$429, U$439: #_3V3#0
U$4, U$5, U$64, U$65, U$125, U$126, U$186, U$187, U$247, U$248, U$308, U$309, U$369, U$370, U$430, U$431: #_GND#0
U$6, U$80, U$141, U$202, U$263, U$324, U$385, U$446: #SHLD#0
U$7, U$8, U$66, U$67, U$127, U$128, U$188, U$189, U$249, U$250, U$310, U$311, U$371, U$372, U$432, U$433: #GND_#0
U$9, U$12, U$68, U$70, U$129, U$131, U$190, U$192, U$251, U$253, U$312, U$314, U$373, U$375, U$434, U$436: #3V3_#0
U$10, U$81, U$142, U$203, U$264, U$325, U$386, U$447: #DTR#0
U$11, U$69, U$130, U$191, U$252, U$313, U$374, U$435: #VIN_#0
U$13, U$71, U$132, U$193, U$254, U$315, U$376, U$437: #1V8_#0
U$14, U$72, U$133, U$194, U$255, U$316, U$377, U$438: #_1V8#0
U$16, U$74, U$135, U$196, U$257, U$318, U$379, U$440: #_VIN#0
U$17, U$75, U$136, U$197, U$258, U$319, U$380, U$441: #_CTS#0
U$18, U$76, U$137, U$198, U$259, U$320, U$381, U$442: #_RTS#0
U$19, U$95, U$156, U$217, U$278, U$339, U$400, U$461: #RXD_#0
U$20, U$96, U$157, U$218, U$279, U$340, U$401, U$462: #TXD_#0
U$21, U$77, U$138, U$199, U$260, U$321, U$382, U$443: #_CLK#0
U$22, U$78, U$139, U$200, U$261, U$322, U$383, U$444: #_WA#0
U$23, U$97, U$158, U$219, U$280, U$341, U$402, U$463: #RXA_#0
U$24, U$98, U$159, U$220, U$281, U$342, U$403, U$464: #TXA_#0
U$26, U$105, U$166, U$227, U$288, U$349, U$410, U$471: SIM_CARD0
U$27, U$106, U$167, U$228, U$289, U$350, U$411, U$472: VOLTAGE_LEVEL0
U$28, U$82, U$143, U$204, U$265, U$326, U$387, U$448: PWR0
U$29, U$36, U$119, U$120, U$180, U$181, U$241, U$242, U$302, U$303, U$363, U$364, U$424, U$425, U$485, U$486: ANT10
U$30, U$107, U$168, U$229, U$290, U$351, U$412, U$473: TEST_POINTS0
U$31, U$35, U$85, U$86, U$146, U$147, U$207, U$208, U$268, U$269, U$329, U$330, U$390, U$391, U$451, U$452: LARA#R60
U$32, U$91, U$152, U$213, U$274, U$335, U$396, U$457: #_RXA#0
U$33, U$83, U$144, U$205, U$266, U$327, U$388, U$449: #_#RST##0
U$34, U$108, U$169, U$230, U$291, U$352, U$413, U$474: PTH_PADS0
U$37, U$39, U$115, U$116, U$176, U$177, U$237, U$238, U$298, U$299, U$359, U$360, U$420, U$421, U$481, U$482: ON0
U$38, U$90, U$151, U$212, U$273, U$334, U$395, U$456: ##PWR_ON#_#0
U$40, U$92, U$153, U$214, U$275, U$336, U$397, U$458: #_TXA#0
U$41, U$93, U$154, U$215, U$276, U$337, U$398, U$459: #_TXD#0
U$42, U$94, U$155, U$216, U$277, U$338, U$399, U$460: #_RXD#0
U$43, U$99, U$160, U$221, U$282, U$343, U$404, U$465: #CLK_#0
U$44, U$100, U$161, U$222, U$283, U$344, U$405, U$466: #WA_#0
U$45, U$87, U$148, U$209, U$270, U$331, U$392, U$453: #RTS_#0
U$46, U$88, U$149, U$210, U$271, U$332, U$393, U$454: #CTS_#0
U$47, U$89, U$150, U$211, U$272, U$333, U$394, U$455: ##RESET#_#0
U$48, U$101, U$162, U$223, U$284, U$345, U$406, U$467: UART0
U$49, U$102, U$163, U$224, U$285, U$346, U$407, U$468: I2S0
U$50, U$109, U$170, U$231, U$292, U$353, U$414, U$475: 1#8V0
U$51, U$103, U$164, U$225, U$286, U$347, U$408, U$469: ORIENTATION0
U$52, U$104, U$165, U$226, U$287, U$348, U$409, U$470: RST0
U$53, U$117, U$178, U$239, U$300, U$361, U$422, U$483: #ON_LED#0
U$54, U$110, U$171, U$232, U$293, U$354, U$415, U$476: 3#3V0
U$56, U$111, U$172, U$233, U$294, U$355, U$416, U$477: UART20
U$57, U$112, U$173, U$234, U$295, U$356, U$417, U$478: GPIO0
U$58, U$113, U$174, U$235, U$296, U$357, U$418, U$479: I2C0
U$59, U$114, U$175, U$236, U$297, U$358, U$419, U$480: #_#ON##0
U$60, U$118, U$179, U$240, U$301, U$362, U$423, U$484: #PWR_LED#0
U$61, U$62, U$121, U$122, U$182, U$183, U$243, U$244, U$304, U$305, U$365, U$366, U$426, U$427, U$487, U$488: ANT20

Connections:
1.8V: C6.1, C7.1, IC1.1, IC1.7, IC1.16, IC3.1, IC3.2, IC3.7, IC3.16, J3.4, ON_LED.2, R1.2, TP3.1, TP9.1, TP15.1, U1.4
1.8V1: C19.1, C20.1, IC2.1, IC2.7, IC2.16, IC4.1, IC4.2, IC4.7, IC4.16, J8.4, ON_LED1.2, R10.2, TP20.1, TP26.1, TP32.1, U3.4
1.8V2: C32.1, C33.1, IC5.1, IC5.7, IC5.16, IC6.1, IC6.2, IC6.7, IC6.16, J12.4, ON_LED2.2, R17.2, TP37.1, TP43.1, TP49.1, U5.4
1.8V3: C45.1, C46.1, IC7.1, IC7.7, IC7.16, IC8.1, IC8.2, IC8.7, IC8.16, J16.4, ON_LED3.2, R24.2, TP54.1, TP60.1, TP66.1, U7.4
1.8V4: C58.1, C59.1, IC9.1, IC9.7, IC9.16, IC10.1, IC10.2, IC10.7, IC10.16, J20.4, ON_LED4.2, R31.2, TP71.1, TP77.1, TP83.1, U9.4
1.8V5: C71.1, C72.1, IC11.1, IC11.7, IC11.16, IC12.1, IC12.2, IC12.7, IC12.16, J24.4, ON_LED5.2, R38.2, TP88.1, TP94.1, TP100.1, U11.4
1.8V6: C84.1, C85.1, IC13.1, IC13.7, IC13.16, IC14.1, IC14.2, IC14.7, IC14.16, J28.4, ON_LED6.2, R45.2, TP105.1, TP111.1, TP117.1, U13.4
1.8V7: C97.1, C98.1, IC15.1, IC15.7, IC15.16, IC16.1, IC16.2, IC16.7, IC16.16, J32.4, ON_LED7.2, R52.2, TP122.1, TP128.1, TP134.1, U15.4
3.3V: C9.+, C10.1, C11.1, C12.1, C13.1, IC1.15, IC3.15, J2.6, J3.3, PWR_LED.2, U1.51, U1.52, U1.53, U2.1
3.3V1: C22.+, C23.1, C24.1, C25.1, C26.1, IC2.15, IC4.15, J7.6, J8.3, PWR_LED1.2, U3.51, U3.52, U3.53, U4.1
3.3V2: C35.+, C36.1, C37.1, C38.1, C39.1, IC5.15, IC6.15, J11.6, J12.3, PWR_LED2.2, U5.51, U5.52, U5.53, U6.1
3.3V3: C48.+, C49.1, C50.1, C51.1, C52.1, IC7.15, IC8.15, J15.6, J16.3, PWR_LED3.2, U7.51, U7.52, U7.53, U8.1
3.3V4: C61.+, C62.1, C63.1, C64.1, C65.1, IC9.15, IC10.15, J19.6, J20.3, PWR_LED4.2, U9.51, U9.52, U9.53, U10.1
3.3V5: C74.+, C75.1, C76.1, C77.1, C78.1, IC11.15, IC12.15, J23.6, J24.3, PWR_LED5.2, U11.51, U11.52, U11.53, U12.1
3.3V6: C87.+, C88.1, C89.1, C90.1, C91.1, IC13.15, IC14.15, J27.6, J28.3, PWR_LED6.2, U13.51, U13.52, U13.53, U14.1
3.3V7: C100.+, C101.1, C102.1, C103.1, C104.1, IC15.15, IC16.15, J31.6, J32.3, PWR_LED7.2, U15.51, U15.52, U15.53, U16.1
5V: D7.A, F1.2
5V1: D17.A, F2.2
5V2: D27.A, F3.2
5V3: D37.A, F4.2
5V4: D47.A, F5.2
5V5: D57.A, F6.2
5V6: D67.A, F7.2
5V7: D77.A, F8.2
!PWR_ON!: D9.A, ON_BTN.3, ON_BTN.4, U1.15
!PWR_ON!1: D19.A, ON_BTN1.3, ON_BTN1.4, U3.15
!PWR_ON!2: D29.A, ON_BTN2.3, ON_BTN2.4, U5.15
!PWR_ON!3: D39.A, ON_BTN3.3, ON_BTN3.4, U7.15
!PWR_ON!4: D49.A, ON_BTN4.3, ON_BTN4.4, U9.15
!PWR_ON!5: D59.A, ON_BTN5.3, ON_BTN5.4, U11.15
!PWR_ON!6: D69.A, ON_BTN6.3, ON_BTN6.4, U13.15
!PWR_ON!7: D79.A, ON_BTN7.3, ON_BTN7.4, U15.15
!RESET!: D10.A, RST_BTN.3, RST_BTN.4, U1.18
!RESET!1: D20.A, RST_BTN1.3, RST_BTN1.4, U3.18
!RESET!2: D30.A, RST_BTN2.3, RST_BTN2.4, U5.18
!RESET!3: D40.A, RST_BTN3.3, RST_BTN3.4, U7.18
!RESET!4: D50.A, RST_BTN4.3, RST_BTN4.4, U9.18
!RESET!5: D60.A, RST_BTN5.3, RST_BTN5.4, U11.18
!RESET!6: D70.A, RST_BTN6.3, RST_BTN6.4, U13.18
!RESET!7: D80.A, RST_BTN7.3, RST_BTN7.4, U15.18
ANT1: D2.1, E2.SIG, U1.56
ANT2: D3.1, E1.SIG, U1.62
ANT3: D12.1, E4.SIG, U3.56
ANT4: D13.1, E3.SIG, U3.62
ANT5: D22.1, E6.SIG, U5.56
ANT6: D23.1, E5.SIG, U5.62
ANT7: D32.1, E8.SIG, U7.56
ANT8: D33.1, E7.SIG, U7.62
ANT9: D42.1, E10.SIG, U9.56
ANT10: D43.1, E9.SIG, U9.62
ANT11: D52.1, E12.SIG, U11.56
ANT12: D53.1, E11.SIG, U11.62
ANT13: D62.1, E14.SIG, U13.56
ANT14: D63.1, E13.SIG, U13.62
ANT15: D72.1, E16.SIG, U15.56
ANT16: D73.1, E15.SIG, U15.62
CTS_1: IC2.5, U3.11
CTS_2: IC2.12, J7.9
CTS_3: IC5.5, U5.11
CTS_4: IC5.12, J11.9
CTS_5: IC7.5, U7.11
CTS_6: IC7.12, J15.9
CTS_7: IC9.5, U9.11
CTS_8: IC9.12, J19.9
CTS_9: IC11.5, U11.11
CTS_10: IC11.12, J23.9
CTS_11: IC13.5, U13.11
CTS_12: IC13.12, J27.9
CTS_13: IC15.5, U15.11
CTS_14: IC15.12, J31.9
CTS_18: IC1.5, U1.11
CTS_33: IC1.12, J2.9
DCD/RXD2_1: TP24.1, U3.8
DCD/RXD2_2: TP41.1, U5.8
DCD/RXD2_3: TP58.1, U7.8
DCD/RXD2_4: TP75.1, U9.8
DCD/RXD2_5: TP92.1, U11.8
DCD/RXD2_6: TP109.1, U13.8
DCD/RXD2_7: TP126.1, U15.8
DCD/RXD2_18: TP7.1, U1.8
DSR/RTS2_1: TP22.1, U3.6
DSR/RTS2_2: TP39.1, U5.6
DSR/RTS2_3: TP56.1, U7.6
DSR/RTS2_4: TP73.1, U9.6
DSR/RTS2_5: TP90.1, U11.6
DSR/RTS2_6: TP107.1, U13.6
DSR/RTS2_7: TP124.1, U15.6
DSR/RTS2_18: TP5.1, U1.6
DTR/TXD2_1: DTR1.2, TP25.1, U3.9
DTR/TXD2_2: DTR2.2, TP42.1, U5.9
DTR/TXD2_3: DTR3.2, TP59.1, U7.9
DTR/TXD2_4: DTR4.2, TP76.1, U9.9
DTR/TXD2_5: DTR5.2, TP93.1, U11.9
DTR/TXD2_6: DTR6.2, TP110.1, U13.9
DTR/TXD2_7: DTR7.2, TP127.1, U15.9
DTR/TXD2_18: DTR.2, TP8.1, U1.9
EN: R2.1, U2.5
EN1: R11.1, U4.5
EN2: R18.1, U6.5
EN3: R25.1, U8.5
EN4: R32.1, U10.5
EN5: R39.1, U12.5
EN6: R46.1, U14.5
EN7: R53.1, U16.5
GND: C1.2, C2.2, C3.2, C4.2, C5.2, C6.2, C7.2, C8.2, C9.-, C10.2, C11.2, C12.2, C13.2, D1.2, D2.2, D3.2, D4.2, D4.5, DTR.1, E1.GND@0, E1.GND@1, E1.GND@2, E1.GND@3, E2.GND@0, E2.GND@1, E2.GND@2, E2.GND@3, IC1.2, IC1.8, IC1.9, IC1.10, IC3.8, IC3.9, IC3.10, J1.A1, J1.A2, J1.A3, J1.A4, J1.C5, J2.5, J3.1, J4.GND, J4.GND2, ON_BTN.1, ON_BTN.2, R3.1, R4.1, R5.1, R6.1, R7.1, RST_BTN.1, RST_BTN.2, SHLD.1, TP4.1, TP10.1, TP16.1, U1.1, U1.3, U1.5, U1.14, U1.20, U1.21, U1.22, U1.30, U1.32, U1.43, U1.50, U1.54, U1.55, U1.57, U1.58, U1.60, U1.61, U1.63, U1.64, U1.65, U1.66, U1.67, U1.68, U1.69, U1.70, U1.71, U1.72, U1.73, U1.74, U1.75, U1.76, U1.77, U1.78, U1.79, U1.80, U1.81, U1.82, U1.83, U1.84, U1.85, U1.86, U1.87, U1.88, U1.89, U1.90, U1.91, U1.92, U1.93, U1.94, U1.95, U1.96, U2.4, U2.EP
GND1: C14.2, C15.2, C16.2, C17.2, C18.2, C19.2, C20.2, C21.2, C22.-, C23.2, C24.2, C25.2, C26.2, D11.2, D12.2, D13.2, D14.2, D14.5, DTR1.1, E3.GND@0, E3.GND@1, E3.GND@2, E3.GND@3, E4.GND@0, E4.GND@1, E4.GND@2, E4.GND@3, IC2.2, IC2.8, IC2.9, IC2.10, IC4.8, IC4.9, IC4.10, J5.GND, J5.GND2, J6.A1, J6.A2, J6.A3, J6.A4, J6.C5, J7.5, J8.1, ON_BTN1.1, ON_BTN1.2, R8.1, R9.1, R12.1, R13.1, R14.1, RST_BTN1.1, RST_BTN1.2, SHLD1.1, TP21.1, TP27.1, TP33.1, U3.1, U3.3, U3.5, U3.14, U3.20, U3.21, U3.22, U3.30, U3.32, U3.43, U3.50, U3.54, U3.55, U3.57, U3.58, U3.60, U3.61, U3.63, U3.64, U3.65, U3.66, U3.67, U3.68, U3.69, U3.70, U3.71, U3.72, U3.73, U3.74, U3.75, U3.76, U3.77, U3.78, U3.79, U3.80, U3.81, U3.82, U3.83, U3.84, U3.85, U3.86, U3.87, U3.88, U3.89, U3.90, U3.91, U3.92, U3.93, U3.94, U3.95, U3.96, U4.4, U4.EP
GND2: C27.2, C28.2, C29.2, C30.2, C31.2, C32.2, C33.2, C34.2, C35.-, C36.2, C37.2, C38.2, C39.2, D21.2, D22.2, D23.2, D24.2, D24.5, DTR2.1, E5.GND@0, E5.GND@1, E5.GND@2, E5.GND@3, E6.GND@0, E6.GND@1, E6.GND@2, E6.GND@3, IC5.2, IC5.8, IC5.9, IC5.10, IC6.8, IC6.9, IC6.10, J9.GND, J9.GND2, J10.A1, J10.A2, J10.A3, J10.A4, J10.C5, J11.5, J12.1, ON_BTN2.1, ON_BTN2.2, R15.1, R16.1, R19.1, R20.1, R21.1, RST_BTN2.1, RST_BTN2.2, SHLD2.1, TP38.1, TP44.1, TP50.1, U5.1, U5.3, U5.5, U5.14, U5.20, U5.21, U5.22, U5.30, U5.32, U5.43, U5.50, U5.54, U5.55, U5.57, U5.58, U5.60, U5.61, U5.63, U5.64, U5.65, U5.66, U5.67, U5.68, U5.69, U5.70, U5.71, U5.72, U5.73, U5.74, U5.75, U5.76, U5.77, U5.78, U5.79, U5.80, U5.81, U5.82, U5.83, U5.84, U5.85, U5.86, U5.87, U5.88, U5.89, U5.90, U5.91, U5.92, U5.93, U5.94, U5.95, U5.96, U6.4, U6.EP
GND3: C40.2, C41.2, C42.2, C43.2, C44.2, C45.2, C46.2, C47.2, C48.-, C49.2, C50.2, C51.2, C52.2, D31.2, D32.2, D33.2, D34.2, D34.5, DTR3.1, E7.GND@0, E7.GND@1, E7.GND@2, E7.GND@3, E8.GND@0, E8.GND@1, E8.GND@2, E8.GND@3, IC7.2, IC7.8, IC7.9, IC7.10, IC8.8, IC8.9, IC8.10, J13.GND, J13.GND2, J14.A1, J14.A2, J14.A3, J14.A4, J14.C5, J15.5, J16.1, ON_BTN3.1, ON_BTN3.2, R22.1, R23.1, R26.1, R27.1, R28.1, RST_BTN3.1, RST_BTN3.2, SHLD3.1, TP55.1, TP61.1, TP67.1, U7.1, U7.3, U7.5, U7.14, U7.20, U7.21, U7.22, U7.30, U7.32, U7.43, U7.50, U7.54, U7.55, U7.57, U7.58, U7.60, U7.61, U7.63, U7.64, U7.65, U7.66, U7.67, U7.68, U7.69, U7.70, U7.71, U7.72, U7.73, U7.74, U7.75, U7.76, U7.77, U7.78, U7.79, U7.80, U7.81, U7.82, U7.83, U7.84, U7.85, U7.86, U7.87, U7.88, U7.89, U7.90, U7.91, U7.92, U7.93, U7.94, U7.95, U7.96, U8.4, U8.EP
GND4: C53.2, C54.2, C55.2, C56.2, C57.2, C58.2, C59.2, C60.2, C61.-, C62.2, C63.2, C64.2, C65.2, D41.2, D42.2, D43.2, D44.2, D44.5, DTR4.1, E9.GND@0, E9.GND@1, E9.GND@2, E9.GND@3, E10.GND@0, E10.GND@1, E10.GND@2, E10.GND@3, IC9.2, IC9.8, IC9.9, IC9.10, IC10.8, IC10.9, IC10.10, J17.GND, J17.GND2, J18.A1, J18.A2, J18.A3, J18.A4, J18.C5, J19.5, J20.1, ON_BTN4.1, ON_BTN4.2, R29.1, R30.1, R33.1, R34.1, R35.1, RST_BTN4.1, RST_BTN4.2, SHLD4.1, TP72.1, TP78.1, TP84.1, U9.1, U9.3, U9.5, U9.14, U9.20, U9.21, U9.22, U9.30, U9.32, U9.43, U9.50, U9.54, U9.55, U9.57, U9.58, U9.60, U9.61, U9.63, U9.64, U9.65, U9.66, U9.67, U9.68, U9.69, U9.70, U9.71, U9.72, U9.73, U9.74, U9.75, U9.76, U9.77, U9.78, U9.79, U9.80, U9.81, U9.82, U9.83, U9.84, U9.85, U9.86, U9.87, U9.88, U9.89, U9.90, U9.91, U9.92, U9.93, U9.94, U9.95, U9.96, U10.4, U10.EP
GND5: C66.2, C67.2, C68.2, C69.2, C70.2, C71.2, C72.2, C73.2, C74.-, C75.2, C76.2, C77.2, C78.2, D51.2, D52.2, D53.2, D54.2, D54.5, DTR5.1, E11.GND@0, E11.GND@1, E11.GND@2, E11.GND@3, E12.GND@0, E12.GND@1, E12.GND@2, E12.GND@3, IC11.2, IC11.8, IC11.9, IC11.10, IC12.8, IC12.9, IC12.10, J21.GND, J21.GND2, J22.A1, J22.A2, J22.A3, J22.A4, J22.C5, J23.5, J24.1, ON_BTN5.1, ON_BTN5.2, R36.1, R37.1, R40.1, R41.1, R42.1, RST_BTN5.1, RST_BTN5.2, SHLD5.1, TP89.1, TP95.1, TP101.1, U11.1, U11.3, U11.5, U11.14, U11.20, U11.21, U11.22, U11.30, U11.32, U11.43, U11.50, U11.54, U11.55, U11.57, U11.58, U11.60, U11.61, U11.63, U11.64, U11.65, U11.66, U11.67, U11.68, U11.69, U11.70, U11.71, U11.72, U11.73, U11.74, U11.75, U11.76, U11.77, U11.78, U11.79, U11.80, U11.81, U11.82, U11.83, U11.84, U11.85, U11.86, U11.87, U11.88, U11.89, U11.90, U11.91, U11.92, U11.93, U11.94, U11.95, U11.96, U12.4, U12.EP
GND6: C79.2, C80.2, C81.2, C82.2, C83.2, C84.2, C85.2, C86.2, C87.-, C88.2, C89.2, C90.2, C91.2, D61.2, D62.2, D63.2, D64.2, D64.5, DTR6.1, E13.GND@0, E13.GND@1, E13.GND@2, E13.GND@3, E14.GND@0, E14.GND@1, E14.GND@2, E14.GND@3, IC13.2, IC13.8, IC13.9, IC13.10, IC14.8, IC14.9, IC14.10, J25.GND, J25.GND2, J26.A1, J26.A2, J26.A3, J26.A4, J26.C5, J27.5, J28.1, ON_BTN6.1, ON_BTN6.2, R43.1, R44.1, R47.1, R48.1, R49.1, RST_BTN6.1, RST_BTN6.2, SHLD6.1, TP106.1, TP112.1, TP118.1, U13.1, U13.3, U13.5, U13.14, U13.20, U13.21, U13.22, U13.30, U13.32, U13.43, U13.50, U13.54, U13.55, U13.57, U13.58, U13.60, U13.61, U13.63, U13.64, U13.65, U13.66, U13.67, U13.68, U13.69, U13.70, U13.71, U13.72, U13.73, U13.74, U13.75, U13.76, U13.77, U13.78, U13.79, U13.80, U13.81, U13.82, U13.83, U13.84, U13.85, U13.86, U13.87, U13.88, U13.89, U13.90, U13.91, U13.92, U13.93, U13.94, U13.95, U13.96, U14.4, U14.EP
GND7: C92.2, C93.2, C94.2, C95.2, C96.2, C97.2, C98.2, C99.2, C100.-, C101.2, C102.2, C103.2, C104.2, D71.2, D72.2, D73.2, D74.2, D74.5, DTR7.1, E15.GND@0, E15.GND@1, E15.GND@2, E15.GND@3, E16.GND@0, E16.GND@1, E16.GND@2, E16.GND@3, IC15.2, IC15.8, IC15.9, IC15.10, IC16.8, IC16.9, IC16.10, J29.GND, J29.GND2, J30.A1, J30.A2, J30.A3, J30.A4, J30.C5, J31.5, J32.1, ON_BTN7.1, ON_BTN7.2, R50.1, R51.1, R54.1, R55.1, R56.1, RST_BTN7.1, RST_BTN7.2, SHLD7.1, TP123.1, TP129.1, TP135.1, U15.1, U15.3, U15.5, U15.14, U15.20, U15.21, U15.22, U15.30, U15.32, U15.43, U15.50, U15.54, U15.55, U15.57, U15.58, U15.60, U15.61, U15.63, U15.64, U15.65, U15.66, U15.67, U15.68, U15.69, U15.70, U15.71, U15.72, U15.73, U15.74, U15.75, U15.76, U15.77, U15.78, U15.79, U15.80, U15.81, U15.82, U15.83, U15.84, U15.85, U15.86, U15.87, U15.88, U15.89, U15.90, U15.91, U15.92, U15.93, U15.94, U15.95, U15.96, U16.4, U16.EP
I2S_CLK_1: IC4.12, J7.3
I2S_CLK_2: IC4.5, U3.36
I2S_CLK_3: IC6.12, J11.3
I2S_CLK_4: IC6.5, U5.36
I2S_CLK_5: IC8.12, J15.3
I2S_CLK_6: IC8.5, U7.36
I2S_CLK_7: IC10.12, J19.3
I2S_CLK_8: IC10.5, U9.36
I2S_CLK_9: IC12.12, J23.3
I2S_CLK_10: IC12.5, U11.36
I2S_CLK_11: IC14.12, J27.3
I2S_CLK_12: IC14.5, U13.36
I2S_CLK_13: IC16.12, J31.3
I2S_CLK_14: IC16.5, U15.36
I2S_CLK_18: IC3.5, U1.36
I2S_CLK_33: IC3.12, J2.3
I2S_RXA_1: IC4.11, J7.4
I2S_RXA_2: IC4.6, U3.37
I2S_RXA_3: IC6.11, J11.4
I2S_RXA_4: IC6.6, U5.37
I2S_RXA_5: IC8.11, J15.4
I2S_RXA_6: IC8.6, U7.37
I2S_RXA_7: IC10.11, J19.4
I2S_RXA_8: IC10.6, U9.37
I2S_RXA_9: IC12.11, J23.4
I2S_RXA_10: IC12.6, U11.37
I2S_RXA_11: IC14.11, J27.4
I2S_RXA_12: IC14.6, U13.37
I2S_RXA_13: IC16.11, J31.4
I2S_RXA_14: IC16.6, U15.37
I2S_RXA_18: IC3.6, U1.37
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

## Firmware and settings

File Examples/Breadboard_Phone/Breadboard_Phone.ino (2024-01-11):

// Include other helper files in this project directory
#include "Breadboard_Phone_Definitions.h"
#include "Breadboard_Phone_Hardware.h"
#include "Breadboard_Phone_Menus.h"

void setup()
{
    // Begin serial and print a message so we know it's working
    Serial.begin(115200);
    Serial.println("Breadboard Phone Demo!");

    // Begin all the hardware on the Breadboard Phone
    beginHardware();
}

void loop()
{
    // Get user input
    updateKeypad();
    
    // Update the display
    selectMenu();

    // No need to go super fast here
    delay(10);
}

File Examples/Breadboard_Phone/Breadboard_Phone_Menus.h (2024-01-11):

#pragma once

#include "Breadboard_Phone_Definitions.h"
#include "Breadboard_Phone_Hardware.h"

////////////////////////////////////////////////////////////////////////////////
// Menu helper functions
////////////////////////////////////////////////////////////////////////////////

void menuHome()
{
    // Display main menu
    String text = "";
    text += "Home\n";
    text += "1-Dial\n";
    text += "2-Text\n";
    text += "3-Audio\n";
    printDisplay(text);

    // Check for button press
    char button = keypad.getButton();
    if ((button >= '0') && (button <= '9'))
    {
        menuIndex = (uint8_t)(button - '0');
    }
}

void menuDial()
{
    // Display dial menu with currently entered number (if any)
    String text = "";
    text += "Number?\n";
    if (destinationNumber.length() == 0)
    {
        text += "*-Back\n";
        text += "#-Speed\n";
    }
    else
    {
        text += "*-Delete\n";
        text += "#-Dial\n";
    }
    text += destinationNumber;
    printDisplay(text);

    // Check for button press
    char button = keypad.getButton();
    if (button == '*')
    {
        // Return or delete pressed
        if (destinationNumber.length() == 0)
        {
            // Return
            if (textMessage.length() == 0)
            {
                menuIndex = MENU_HOME;
            }
            else
            {
                menuIndex = MENU_TEXT;
            }
        }
        else
        {
            // Delete
            destinationNumber.remove(destinationNumber.length() - 1, 1);
        }
    }
    else if (button == '#')
    {
        // Enter pressed
        if (destinationNumber.length() == 0)
        {
            // No number entered, go to speed dial menu
            menuIndex = MENU_SPEED_DIAL;
        }
        else
        {
            // Number entered
            if (textMessage.length() == 0)
            {
                // No text message, dial number
                printDisplay("Calling...");
                callActive = true;
                dialNumber();
                menuIndex = MENU_CALL;
            }
            else
            {
                // Text message, send text
                printDisplay("Sending...");
                sendText();
                menuIndex = MENU_HOME;
            }
        }
    }
    else if (button > 0)
    {
        // Number pressed, add to number
        destinationNumber += button;
    }
}

void menuSpeedDial()
{
    // Display speed dial menu
    String text = "";
    text += "Contact?\n";
    text += "*-Back\n";
    text += "#-Dial\n";
    text += speedDialNames[speedDialIndex];
    printDisplay(text);

    // Check for button press
    char button = keypad.getButton();
    if (button == '*')
    {
        // Return pressed
        menuIndex = MENU_DIAL;
        speedDialIndex = 0;
    }
    else if (button == '#')
    {
        // Enter pressed, set destination number from speed dial contact list
        destinationNumber = speedDialNumbers[speedDialIndex];
        if (textMessage.length() == 0)
        {
            // No text message, dial number
            printDisplay("Calling...");
            callActive = true;
            dialNumber();
            menuIndex = MENU_CALL;
        }
        else
        {
            // Text message, send text
            printDisplay("Sending...");
            sendText();
            menuIndex = MENU_HOME;
        }
    }
    else if (button > 0)
    {
        // Number pressed, set speed dial index
        speedDialIndex = button - '0';
    }
}

void menuCall()
{
    // Display call menu with currently dialed number or speed dial contact name
    String text = "";
    text += "Call\n";
    text += "*-Hang up\n";
    if (speedDialIndex > 0)
    {
        text += speedDialNames[speedDialIndex];
    }
    else
    {
        text += destinationNumber;
    }
    printDisplay(text);

    // Check for button press
    char button = keypad.getButton();
    if ((button == '*') || (callActive == false))
    {
        // Hang up pressed or call ended
        hangUp();
        menuIndex = MENU_HOME;
        destinationNumber = "";
        speedDialIndex = 0;
    }
}

void menuRing()
{
    // Display ring alert message
    String text = "";
    text += "RING RING\n";
    text += "*-Hang up\n";
    text += "#-Answer\n";
    printDisplay(text);

    // Check for button press
    char button = keypad.getButton();
    if (button == '*')
    {
        // Hang up pressed
        neopixelWrite(RGB_BUILTIN, 0, ledBrightness, 0);
        hangUp();
        menuIndex = MENU_HOME;
    }
    else if (button == '#')
    {
        // Answer pressed
        neopixelWrite(RGB_BUILTIN, 0, ledBrightness, 0);
        callActive = true;
        answerCall();
        menuIndex = MENU_CALL;
    }

    // Create pulsing effect with RGB LED
    neopixelWrite(RGB_BUILTIN, 0, 0, (millis() / 4) & 0xFF);
}
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

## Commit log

2023-09-07 Add initial schematic and layout
    [SparkFun_LTE_Stick_LARA_R6.brd, SparkFun_LTE_Stick_LARA_R6.sch]
2023-09-08 End of day commit
    Extend board length
    Start adding passives
    Plan more routing
    [SparkFun_LTE_Stick_LARA_R6.brd, SparkFun_LTE_Stick_LARA_R6.sch]
2023-09-11 Finish initial layout of v01
    Change UART2, I2C, and GPIO pins to only be accessible via test points
    Shrink board length to 3" again
    Set initial header pinouts
    Add decoupling capacitors
    Route all air wires
    Route USB and RF traces with proper impedance
    [SparkFun_LTE_Stick_LARA_R6.brd, SparkFun_LTE_Stick_LARA_R6.sch]
2023-09-13 Design review updates
    Extend board length to 3.25"
    Remove u.FL connectors
    Rename UART pins to match u-blox naming
    Add Reset and PWR_ON buttons and header pads
    Add power LEDs
    Add fiducials
    Add 100uF bulk capacitor
    Add decoupling capacitors for LARA-R6
    Move SIM ESD diode
    Move GPIO4 test point
    Connect GPIO3 to test point
    Add pulldown to RTS
    Connect DTR to GND via jumper
    Nudge SMA connectors to align with board edge
    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
    [SparkFun_LTE_Stick_LARA_R6.brd, SparkFun_LTE_Stick_LARA_R6.sch]
2023-09-14 Design Review Updates
    Add diodes to PWR_ON and RESET PTH pads to protect against higher voltage inputs
    Move R7 to other side of level shifter
    Add SIM card outline to bottom silk
    Prevent bridging between pads of level shifters
    Remove 5V PTH pad
    Add dueling diodes to VREG input
    [SparkFun_LTE_Stick_LARA_R6.brd, SparkFun_LTE_Stick_LARA_R6.sch]
2023-09-14 Design Review Updates
    Add note to silkscreen about voltage level for PTH pads and test points
    Move PWR LED via away from USB trace
    Adjust measure for SIM card
    Add ordering instructions
    [SparkFun_LTE_Stick_LARA_R6.brd]
2023-09-15 Design review updates
    Update Eagle libraries to fix vector fonts for some symbols
    Add GND vias near SIM holder pads
    Add max input voltage for VREG
    Straighten USB trace near connector (N$10)
    Fix trace on ANT1 ESD pad
    [SparkFun_LTE_Stick_LARA_R6.brd, SparkFun_LTE_Stick_LARA_R6.sch]
2023-09-15 Add v01 production files
    [SparkFun_LTE_Stick_LARA_R6-Panel.GBL, SparkFun_LTE_Stick_LARA_R6-Panel.GBO, SparkFun_LTE_Stick_LARA_R6-Panel.GBP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]
2023-09-15 Clean up design
    Increase frame to ledger size
    Arrange test points in schematic to match physical layout
    Add impedance calculations to schematic
    Update LED VALUE attributes with color in schematic
    Add silkscreen labels to test points
    Decrease font size of top buzzard labels to make tails more visible
    [SparkFun_LTE_Stick_LARA_R6.brd, SparkFun_LTE_Stick_LARA_R6.sch]
2023-10-17 v10 updates
    Bump version number to v10
    Add AT Commands Manual
    Add Application Development App Note
    Add Audio App Note
    Fix text in Antenna Connectors section to be "Coplanar Waveguide Calculation"
    Reposition D7 and D8 so text is horizontal
    Change material to TG155 in ordering instructions
    Nudge some vias to avoid silk
    Shrink pin label size to 0.0375 so flags are visible
    Replace PON with ON
    Appaned "_LED" to LED jumpers
    [SparkFun_LTE_Stick_LARA_R6.brd, SparkFun_LTE_Stick_LARA_R6.sch]
2023-10-17 Add v10 Panel
    [SparkFun_LTE_Stick_LARA_R6-Panel.brd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]
2023-10-17 Change SMA connector PROD_ID
    [SparkFun_LTE_Stick_LARA_R6-Panel.brd, SparkFun_LTE_Stick_LARA_R6.brd, SparkFun_LTE_Stick_LARA_R6.sch]
2023-11-15 v11 - Label SMA connectors in silkscreen
    [SparkFun_LTE_Stick_LARA_R6-Panel.brd, SparkFun_LTE_Stick_LARA_R6.brd, SparkFun_LTE_Stick_LARA_R6.sch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]
2023-12-12 Docs Update
    Initial commit to update software sections for m-center & Arduino library.
2023-12-15 Swap 100uF capacitor for new alternative
    [SparkFun_LTE_Stick_LARA_R6-Panel.brd, SparkFun_LTE_Stick_LARA_R6.brd, SparkFun_LTE_Stick_LARA_R6.sch]
2023-12-20 Docs update
    Updating docs with board files & Arduino/m-center sections.
2024-02-06 Docs Update
    Updating docs to switch from "Hard Copy" to "Print View"

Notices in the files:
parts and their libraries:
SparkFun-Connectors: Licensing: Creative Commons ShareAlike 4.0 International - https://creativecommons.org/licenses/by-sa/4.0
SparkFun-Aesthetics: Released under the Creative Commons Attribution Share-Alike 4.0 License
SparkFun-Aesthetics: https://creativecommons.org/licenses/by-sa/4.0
